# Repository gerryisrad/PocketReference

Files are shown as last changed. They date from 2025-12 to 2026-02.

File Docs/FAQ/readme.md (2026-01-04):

# PocketMage FAQ

---

#### Helpful Links

[PocketMage.org](https://pocketmage.org/)

[PocketMage - GitHub](https://github.com/ashtf8/PocketMage_PDA)

[PocketMage - Discord](https://discord.gg/KSCapSf4XH)

[Ashtf - YouTube](https://www.youtube.com/@ashtf)

[Ashtf - Patreon](patreon.com/Ashtf)

---

#### General Information

###### **What is PocketMage?**

PocketMage is a hackable PDA device focused on productivity. You can use it to take notes, keep track of tasks, journal, schedule your week, and much more. PocketMage is a hackable revival of the classic PDA-style device. The device features a dual-screen setup with a large E Ink main display and a smaller OLED secondary display. It also has a clamshell design with a clear shell and a full tactile thumb keyboard. PocketMage is fully open-source hardware and software, making it ideal for hacking and add-ons!

###### **How much is the kit?**

The PocketMage final production kit isn't released yet and the price isn't set in stone! That being said, the target price is around the $150 mark for a full kit.

###### **How hard is it to build the kit?**

The kit is designed so that **anyone can build it!** The only tool you need is one allen key, and the kit requires no special skills in software or hardware. There is **no soldering**, **no programming, and no electronics** involved in the build process.

###### **Will I be able to get PocketMage if I live outside the USA?**

We plan to ship PocketMage all around the world!

###### **When can I order?**

There is no set release date for the PocketMage kit at this moment, but once the beta production run is complete and the software has some time to mature, we will move on to the final production! See below for how to get notified when the kit releases!

###### **How can I get notified when the kit releases?**

Visit [PocketMage.org](https://pocketmage.org/) and click the purple "Join the Mailing List!" button to sign up for an email notification.

###### **How can I keep up with the PocketMage project?**

You can subscribe to [Ashtf's YouTube Channel](https://www.youtube.com/@ashtf) for video-style updates, [Ashtf's Patreon](patreon.com/Ashtf) for exclusive weekly written updates, and [The PocketMage Discord Server](https://discord.gg/KSCapSf4XH) for community-driven updates!

---

#### Building and Operating the PocketMage

###### **Where is the build guide?**

The video build guide can be found [here.](https://youtu.be/2aNcC0qCK1o?si=HKqUIyK0ZPkjqzQI)

###### **Is there a guide on the key operations?**

Yes! That guide can be found [here.](https://github.com/ashtf8/PocketMage_PDA/tree/main/Docs/Command%20Manual)

###### **How do I flash the firmware?**

First, carefully **remove the battery** out of your PocketMage (pull carefully on the plastic connector). Then, ensure the DIP switch for programming mode is switched to the ON position. Next, hold the power button while plugging your PocketMage into your computer, **nothing should happen**. Next, navigate to [The Web Flasher](https://ashtf8.github.io/PocketMage_PDA/) in a **chrome-based browser** and select your firmware version. The **most recent stable build** is recommended. If you would like to keep your saved settings, ensure that the "Preserve user data during installation" check box is **checked**. Next, hit the flash button and select the PocketMage from the list of USB devices. Once the flashing is done, unplug your PocketMage and re-insert the battery. PocketMage should boot up automatically!

###### **What SD card can I use?**

You can use any microSD card up to 32gb. **8gb is recommended** since PocketMage files are small and require very little storage. The smaller the SD card you use, the faster the PocketMage will be. SD cards **MUST** be formatted to **FAT32** format.

###### **Where are the CAD files?**

Currently CAD files are available only to Beta Testers. These files will be released to the public alongside the release of the final production PocketMage. If you are a Beta Tester, you can find the password-protected .zip file [here](https://github.com/ashtf8/PocketMage_PDA/tree/main/Docs/CAD) and the password in the beta Discord channel.

###### **Where can I get an extra battery?**

International kits do not come with a battery because of shipping regulations. Battery links for common countries can be found [here.](https://pocketmage.org/get/)

###### **What is the programming mode switch?**

The programming mode switch allows you to program and debug the PocketMage. Internally, it connects the USB port directly to the microcontroller, bypassing the USB and battery charge controller. You may keep programming mode on and use the device as normal with no issues, but your charging will be limited to 500mA as opposed to fast charging when programming mode is turned off.

#### Common Issues

---

###### **My dictionary isn't working!**

The English dictionary isn't installed on the PocketMage out of the box and needs to be downloaded to the SD card. Find the dictionary files [here.](https://github.com/ashtf8/PocketMage_PDA/tree/main/Docs/Dictionary%20(OPTED)) Simply connect your PocketMage to your computer using the USB app and drop all the .txt files into the dictionary folder!

###### **I can't flash the firmware!**

Ensure that: Your battery is unplugged and the programming mode DIP switch is set to ON.

###### **I found a software bug!**

Please report the bug in detail on the [GitHub issues page](https://github.com/ashtf8/PocketMage_PDA/issues) and include steps to reproduce. We will get to it when we can!

###### **My SD card isn't working!**

First, ensure that your SD card is below 32gb. The recommended size is 16gb, the smaller the SD card the faster the PocketMage will be. Next, ensure that your SD card is formatted to FAT32. It will not work unless it's formatted to FAT32.

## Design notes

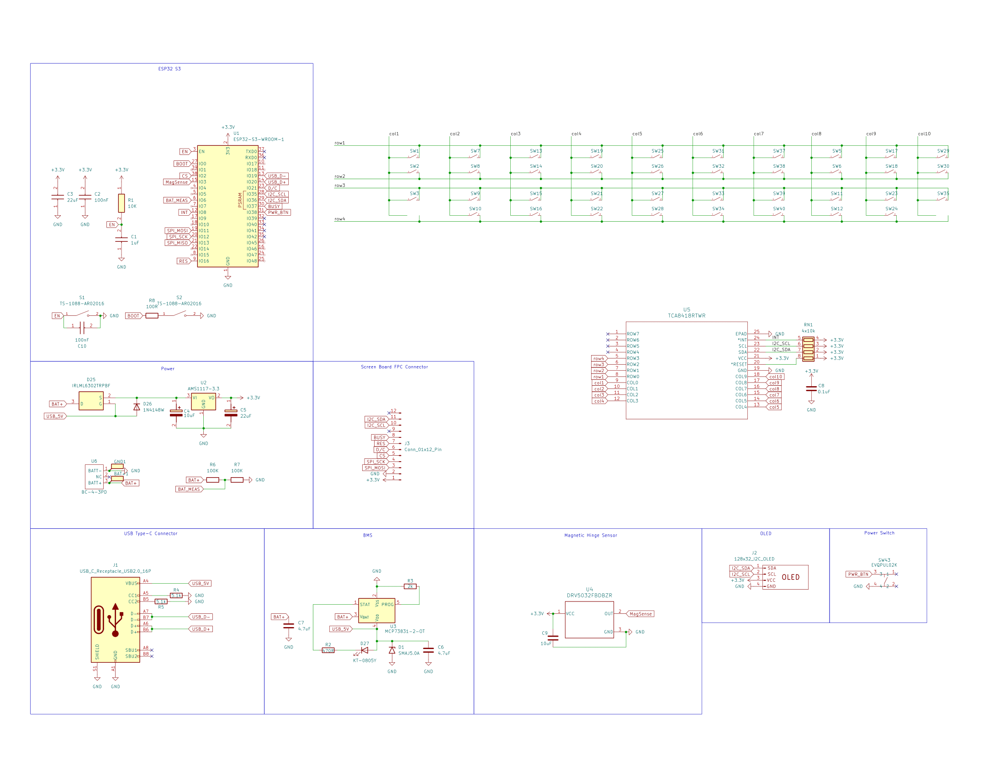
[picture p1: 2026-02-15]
Docs/Documents & Advanced/PCB/SCRAPPED V3/EXPORTED SVG/Schematic-1.png

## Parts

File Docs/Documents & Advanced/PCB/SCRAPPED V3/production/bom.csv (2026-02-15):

Designator | Footprint | Quantity | Value | LCSC Part #
BAT+1, GND1 | TestPoint_Pad_D1.5mm | 2 | TestPoint_Flag
C1 | CAPC2012X135N | 1 | 1uF | CL21B105KBFNNNE
C10, C2, C9 | CAPC2012X95N | 3 | 100nF | CC0805KRX7R9BB104
C3 | CAPC2012X140N | 1 | 22uF | CL21A226MAQNNNE
C4, C5, C6, C7 | 0805 | 4 | 4.7uF | CL21A475KAQNNNE
C8 | 0402 | 1 | 0.1uF | CL05B104KO5NNNC
D1 | D_SMA | 1 | SMAJ5.0A
D25 | SOT95P237X112-3N | 1 | IRLML6302TRPBF | IRLML6302TRPBF
D26 | D_SOD-123 | 1 | 1N4148W | 1N4148W
D27 | 0805 | 1 | KT-0805Y | KT-0805Y
J1 | USB_C_Receptacle_G-Switch_GT-USB-7010ASV | 1 | USB_C_Receptacle_USB2.0_16P | GT-USB-7010ASV
J2 | 128x32 I2C OLED | 1 | 128x32_I2C_OLED
J3 | AFC01-S12FCA-00 | 1 | Conn_01x12_Pin | AFC01-S12FCA-00:AFC01-S12FCA-00
R1, R9 | 0805 | 2 | 10K | 0805W8F1002T5E
R10 | 0603 | 1 | 20k | 0603WAF2002T5E
R11, R3 | 0805 | 2 | 2k | 0805W8F2001T5E
R2 | 0805 | 1 | 470R | 0805W8F4700T5E
R4, R5 | 0603 | 2 | 5.1k | 0603WAF5101T5E
R6, R7 | 1812 | 2 | 100K | FRC1812F1003TS
R8 | 1206 | 1 | 100R | 1206W4F1000T5E
RN1 | R_Array_Concave_4x0603 | 1 | 4x10k | 4D03WGJ0103T5E
S1, S2 | SW_TS-1088-AR02016 | 2 | TS-1088-AR02016 | TS-1088-AR02016
SW1, SW10, SW11, SW12, SW13, SW14, SW15, SW16, SW17, SW18, SW19, SW2, SW20, SW21, SW22, SW23, SW24, SW25, SW26, SW27, SW28, SW29, SW3, SW30, SW31, SW32, SW33, SW34, SW35, SW37, SW38, SW39, SW40, SW5, SW6, SW7, SW8, SW9 | contact_pad_SINGLE | 38 | ~
SW43 | EVQPUL02K | 1 | EVQPUL02K | EVQPUL02K
TP1, TP2 | TestPoint_Pad_3.0x3.0mm | 2 | TestPoint
U1 | ESP32-S3-WROOM-1 | 1 | ESP32-S3-WROOM-1 | ESP32-S3-WROOM-1
U2 | SOT-223-3_TabPin2 | 1 | AP2114H-3.3TRG1 | AP2114H-3.3TRG1
U3 | SOT-23-5 | 1 | MCP73831-2-OT | MCP73831-2-OT
U4 | SOIC-8_3.9x4.9mm_P1.27mm | 1 | PCF8563T
U5 | RTW24_2P45X2P45 | 1 | TCA8418RTWR | TCA8418RTWR
U6 | BC-4-3PD | 1 | BC-4-3PD | BC-4-3PD
Y1 | Crystal_SMD_3215-2Pin_3.2x1.5mm | 1 | Crystal_32.768kHz | XKXGI-SUA-32.768K

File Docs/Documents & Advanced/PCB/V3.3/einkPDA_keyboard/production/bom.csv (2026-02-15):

Designator | Footprint | Quantity | Value | LCSC Part #
BZ1 | BUZ-SMD_3P_L5.0-W5.0-P3.50-TL | 1 | Buzzer | C781883
C1, C20, C6 | 0603 | 3 | 1uF | C15849
C10, C23, C24, C26, C28, C29, C30, C31, C32 | 0805 | 9 | 10uF | C15850
C11 | 0603 | 1 | 4.7pF | C1669
C12, C13, C14, C16 | 1206 | 4 | 4.7uF | C29823
C15, C17 | 0805 | 2 | .1uF | C28233
C19, C7, C8 | 0402 | 3 | 0.1uF | C1525
C2, C9 | 0805 | 2 | 100nF | C49678
C21, C22, C3 | 0805 | 3 | 22uF | C45783
C25 | 0805 | 1 | 4.7uF | C1779
C27 | 0603 | 1 | 22nF | C21122
D1 | 0805 | 1 | KT-0805Y | C2296
D2 | D_SOD-123 | 1 | MBR0530 | C77336
D3 | D_SOD-123F | 1 | SM4007 | C64898
D5 | D_SOD-323 | 1 | D_Schottky | C191023
F1 | 1206 | 1 | SMD1206-500-6V | C2760308
FB1, FB2, FB3 | 0603 | 3 | FerriteBead | C85831
J1 | USB-TYPE-C-SMD_TYPE-C-16P-QTWT | 1 | USB_C_Receptacle_USB2.0_16P | C5187472
J2, J5 | AFC01-S12FCA-00 | 2 | Conn_01x12_Pin | C262661
J3 | FPC-SMD_AFC24-S26FIA [DUAL-SIDE] | 1 | Conn_01x26_Pin | C262684
J4 | TF-SMD_503398-1892 | 1 | Micro_SD_Card | C428492
L1 | L_Chilisin_BMRx00060630 | 1 | 10uH | C5189958
L2 | L_Ferrocore_DLG-0504 | 1 | 1uH | C2929426
L3 | L_Wurth_WE-LQSH-3012 | 1 | 2.2uH | C19734
Q1 | SOT-23 | 1 | MMBT3904 | C20526
R1, R14, R17, R9 | 0805 | 4 | 10K | C17414
R10 | 0603 | 1 | 20k | C4184
R11, R16 | 0805 | 2 | 2k | C17604
R12 | 0805 | 1 | 1.8M | C17399
R13 | 0805 | 1 | 205k | C218417
R15 | 0805 | 1 | 470R | C17710
R18 | 0603 | 1 | 10k | C25804
R2, R8 | 0603 | 2 | 100R | C22775
R20 | 0805 | 1 | 680k | C17797
R3 | 0603 | 1 | 4.7k | C23162
R6, R7 | 0603 | 2 | 100K | C25803
RN1, RN2, RN3, RN4 | R_Array_Concave_4x0603 | 4 | 4x10k | C29718
SW1, SW10, SW11, SW12, SW13, SW14, SW15, SW16, SW17, SW18, SW19, SW20, SW21, SW22, SW23, SW24, SW25, SW26, SW27, SW28, SW29, SW3, SW30, SW31, SW32, SW33, SW34, SW35, SW37, SW38, SW39, SW40, SW5, SW6, SW7, SW9 | contact_pad_SINGLE | 36 | ~
SW2 | contactPad_cutoutR | 1 | ~
SW4 | 2X_DIP_DHN-02-V-TR | 1 | SW_DIP_x02 | C224995
SW43 | SW-SMD_TS24CA | 1 | EVQPUL02K | C393942
SW8 | contactPad_cutoutL | 1 | ~
TH1 | 0603 | 1 | NTC | C76589
TP1, TP2 | TestPoint_Pad_1.0x1.0mm | 2 | TestPoint
U1 | ESP32-S3-WROOM-1 | 1 | ESP32-S3-WROOM-1 | C2913202
U10 | UQFN-10_1.4x1.8mm_P0.4mm | 1 | TS3USB30ERSWR | C73880
U2 | SOT-23-6 | 1 | USBLC6-2SC6 | C7519
U3 | Texas_DRC0010J_ThermalVias | 1 | TPS63001 | C28060
U4 | SOIC-8_3.9x4.9mm_P1.27mm | 1 | PCF8563T | C7440
U5 | RTW24_2P45X2P45 | 1 | TCA8418RTWR | C138713
U6 | JST_PH_2P_P2.00mm | 1 | C2764211 | C2764211
U7 | SOT-23-5 | 1 | TPS61040DBV | C7722
U9 | IC_MP2722GRH-0000-Z | 1 | MP2722GRH-0000-Z | C20099551
Y1 | Crystal_SMD_3215-2Pin_3.2x1.5mm | 1 | Crystal_32.768kHz | C5213671

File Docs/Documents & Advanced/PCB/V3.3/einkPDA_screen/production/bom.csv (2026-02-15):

Designator | Footprint | Quantity | Value | LCSC Part #
C1, C10, C3, C4, C5, C6, C7, C8, C9 | 0402 | 9 | 1uF | CL05A105KA5NQNC
C11 | 0805 | 1 | 4.7uF | CL21A475KAQNNNE
C12, C2 | 0402 | 2 | 4.7uF | CL05A475MP5NRNC
C13, C14 | 0402 | 2 | 0.1uF | CL05B104KO5NNNC
D1, D2, D3 | D_SOD-123 | 3 | MBR0530 | MBR0530
J2 | AFE03-S25FMA-1H | 1 | ~ | AFE03-S25FMA-1H
J3 | TouchSlider-9_50x10mm | 1 | CapacitiveTouch
J4 | AFC01-S12FCA-00 | 1 | Conn_01x12_Pin | AFC01-S12FCA-00
L1 | L_Cenker_CKCS5020 | 1 | 10uH | SWPA5020S100MT
Q1 | SOT-323_SC-70 | 1 | Si1308EDL | Si1308EDL
R1 | 0603 | 1 | 1R | 0603WAF100KT5E
R2 | 0805 | 1 | 10k | 0805W8F1002T5E
R3 | 0603 | 1 | 75k | 0603WAF7502T5E
RN1 | R_Array_Concave_4x0603 | 1 | 4x10k | 4D03WGJ0103T5E
U1 | UQFN-20_3x3mm_P0.4mm | 1 | MPR121QR2 | MPR121QR2

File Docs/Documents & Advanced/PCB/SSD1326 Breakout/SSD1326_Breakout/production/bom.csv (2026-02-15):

Designator | Footprint | Quantity | Value | LCSC Part #
C1 | 0805 | 1 | 10uF
C2, C6 | 1206 | 2 | 4.7uF
C3 | 0603 | 1 | 4.7pF
C4, C5 | CP_EIA-3216-18_Kemet-A | 2 | 4.7uF
C7, C8 | 0805 | 2 | .1uF
D1 | D_SOD-123 | 1 | MBR0530
J1 | FPC-SMD_AFC24-S26FIA [DUAL-SIDE] | 1 | Conn_01x26_Pin
J2 | PinHeader_1x05_P2.54mm_Vertical | 1 | Conn_01x05_Pin
L1 | L_Chilisin_BMRx00060630 | 1 | 10uH
R1 | 0805 | 1 | 1.8M
R2 | 0805 | 1 | 205k
R3, R4 | 0805 | 2 | 10k
R5 | 0805 | 1 | 680k
U1 | SOT-23-5 | 1 | TPS61040DBV

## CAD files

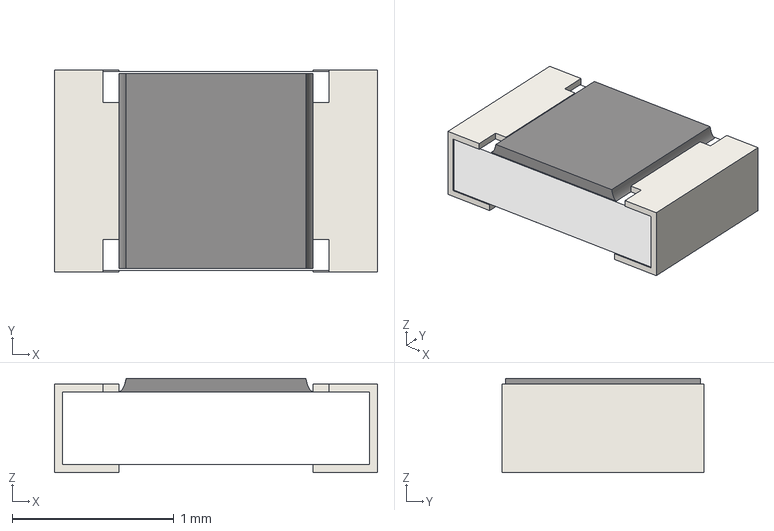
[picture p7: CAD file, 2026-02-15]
Docs/Documents & Advanced/PCB/SCRAPPED V3/import/LIB_0805W8F1002T5E/0805W8F1002T5E/3D/0805W8F1002T5E.stp
2.00 x 1.25 x 0.585 mm

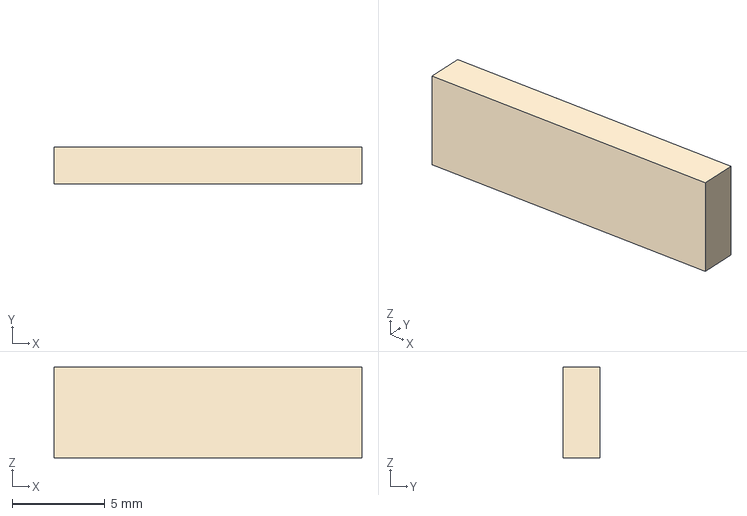
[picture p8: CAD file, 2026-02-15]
Docs/Documents & Advanced/PCB/V3.3/C262684 v2.step
16.6 x 2.00 x 4.90 mm

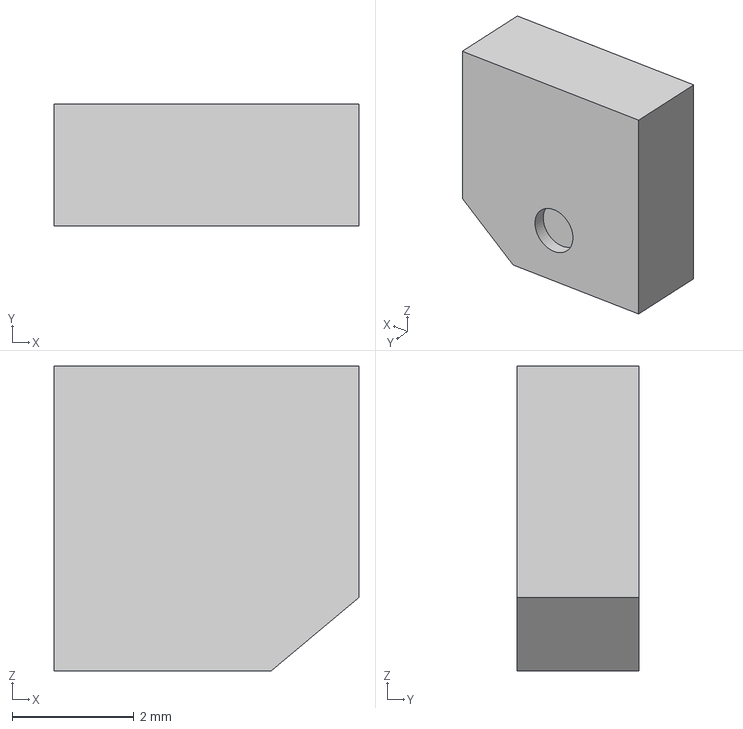
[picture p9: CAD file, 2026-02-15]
Docs/Documents & Advanced/PCB/V3.3/einkPDA_keyboard/JLC_Parts/C781883 v1.step
5.00 x 2.00 x 5.00 mm

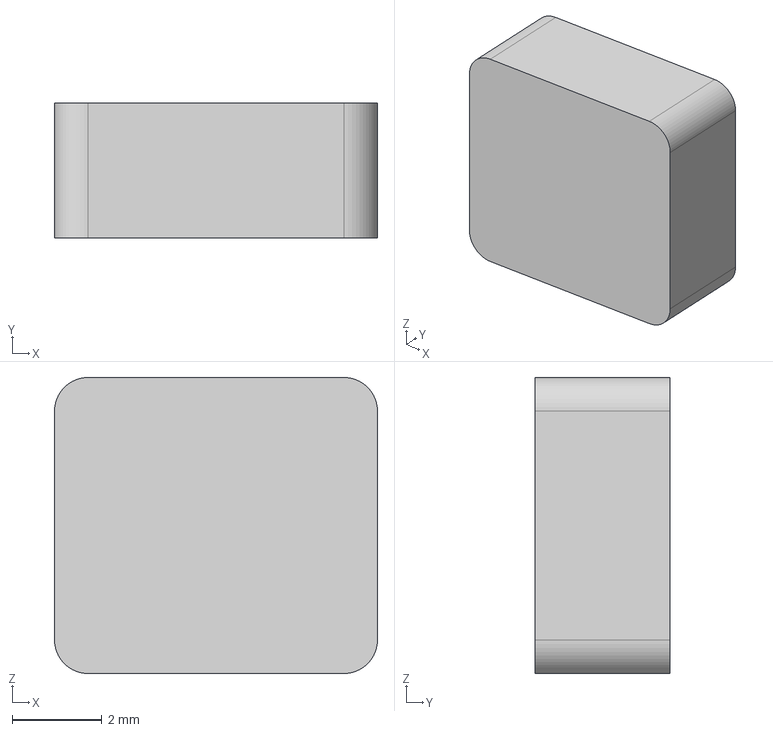
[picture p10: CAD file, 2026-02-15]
Docs/Documents & Advanced/PCB/V3.3/einkPDA_keyboard/JLC_Parts/C5189958 v3.step
7.20 x 3.00 x 6.60 mm

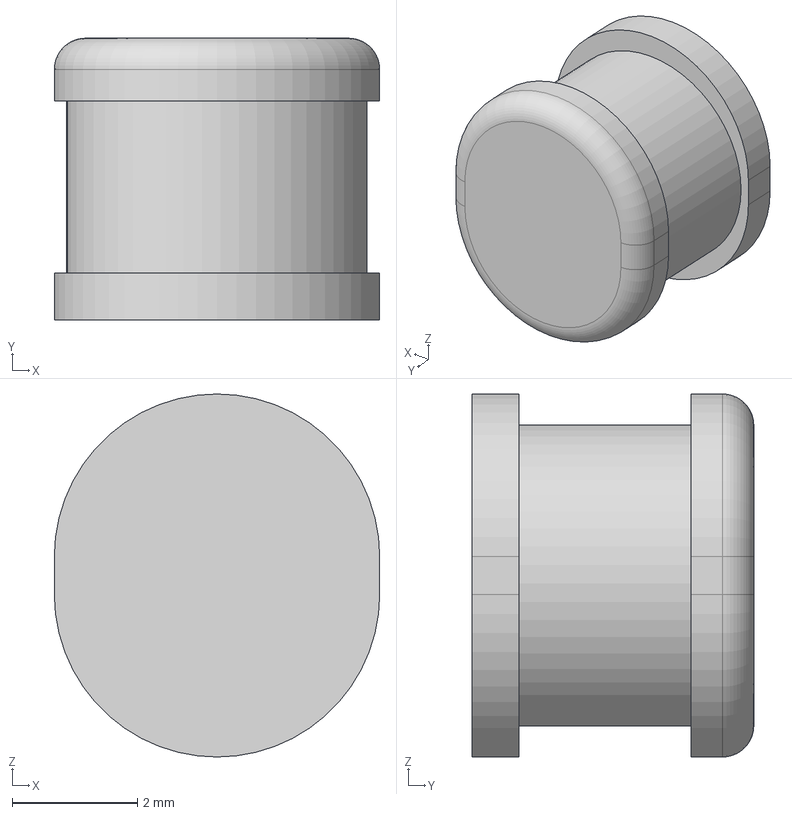
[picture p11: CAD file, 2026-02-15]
Docs/Documents & Advanced/PCB/V3.3/einkPDA_keyboard/JLC_Parts/C2929426 v4.step
5.20 x 4.50 x 5.80 mm

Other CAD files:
Docs/Documents & Advanced/PCB/SCRAPPED V3/import/LIB_0805W8F1002T5E/0805W8F1002T5E/Allegro/resc2013x65n.psm
Docs/Documents & Advanced/PCB/SCRAPPED V3/import/LIB_0805W8F1002T5E/0805W8F1002T5E/DEHDL/0805w8f1002t5e/chips/chips.prt
Docs/Documents & Advanced/PCB/V1/einkPDA_keyboard/import/LIB_0805W8F1002T5E/0805W8F1002T5E/Allegro/resc2013x65n.psm
Docs/Documents & Advanced/PCB/V1/einkPDA_keyboard/import/LIB_0805W8F1002T5E/0805W8F1002T5E/DEHDL/0805w8f1002t5e/chips/chips.prt
Docs/Documents & Advanced/PCB/V2/einkPDA_keyboard/import/LIB_0805W8F1002T5E/0805W8F1002T5E/Allegro/resc2013x65n.psm
Docs/Documents & Advanced/PCB/V2/einkPDA_keyboard/import/LIB_0805W8F1002T5E/0805W8F1002T5E/DEHDL/0805w8f1002t5e/chips/chips.prt
Docs/Documents & Advanced/PCB/V3.1/einkPDA_keyboard/import/LIB_0805W8F1002T5E/0805W8F1002T5E/Allegro/resc2013x65n.psm
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

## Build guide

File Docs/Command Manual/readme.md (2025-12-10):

# PocketMage Keystrokes Guide
This is a guide on common key combinations and commands on the PocketMage PDA device. The guide is split up into sections based on application.

---
## General Keystrokes (work in almost any app)
- **(FN) + ( < )** | Exit or back button
- **(FN) + ( > )** | Save document
- **(FN) + ( o )** | Clear Line
- **(FN) + (Key)** | FN layer keymapping (legends on the PCB)
- **(SHFT) + (key)** | Capital letter
- **( o ) OR (ENTER)** | Select button

---
## Home App
### Entering an OS app
Type an app's name to enter that app. For example, to enter calendar, type "calendar". You can type the name as it appears on the screen or use a shortcut. For example, typing "cal" also enters the calendar.

### Entering a 3rd party app
For 3rd party apps, type the letter of the slot that app is installed in. For example if you have the Calc app installed in the first app slot, type "a" to enter the app.

### Other commands
Many other commands can be done from the homescreen, including all of the settings commands and some other fun ones for you to discover!

---
## TXT App
- **(FN) + ( < )** | Exit app
- **(FN) + ( > )** | Save document
- **(FN) + ( o )** | Enter filesystem (loading files)
- **(FN) + (Key)** | FN layer keymapping (legends on the PCB)
- **(SHFT) + (key)** | Capital letter
- **(ENTER)** | Create a new line
- **(SHFT) + ( < )** | Change text style (body, heading, etc.)
- **(SHFT) + ( > )** | Change formatting (bold, italics, etc.)
- **Scroll Bar** | Swipe up or down to scroll through the document

---
## FILEWIZ
- **(FN) + ( < )** | Exit app
- **( < ) AND ( > )** | Scroll left and right
- **( o ) OR (ENTER)** | Select file or folder
- **( 0 ) TO ( 9 )** | Select recent file
- **( BKSP )** | Go back a filesystem level

---
## USB
Plug in the PocketMage to your PC to view the files. Eject and exit the app when you're finished.
- **(FN) + ( < )** | Exit app

---
## Settings
Type the setting as it appears on the screen to change it. Some examples are given below. Note: all settings are case-insensitive, meaning that you can type in all lowercase. All of these settings are also available from the home menu command bar if you memorize them.
- TimeSet [HH]:[MM] -> TimeSet 15:46
- DateSet YYYYMMDD -> DateSet 20251230
- ShowYear [bool] -> ShowYear t
- Timeout [int] -> Timeout 300
- **(FN) + ( < )** | Exit app

---
## Tasks
- **( N )** | Create a new task, follow on-screen prompts
- **(ENTER)** | Enter information into prompt
- **( 0 ) TO ( 9 )** | Select task for editing
- **(FN) + ( < )** | Exit app

---
## Calendar
Type commands to navigate dates or create events. All commands are case-insensitive.

### Month View
- **jan 2025 / feb 2030 / etc.** | Jump to month and year
- **20251225** | Jump to exact date (YYYYMMDD)
- **14** | Jump to a day in the current month
- **( N )** | New event
- **(FN) + ( < )** | Exit app

### Week View
- **sun, mon, tue, wed, thu, fri, sat** | Jump to weekday in the viewed week
- **( N )** | New event
- **(FN) + ( < )** | Exit app

### Day View
- **( N )** | New event for selected day
- **1, 2, 3, ...** | Open event by index
- **(FN) + ( < )** | Exit app

---
## Journal
Type a date to open or create a journal entry. Commands are case-insensitive.

- **( T )** | Open today’s journal entry
- **YYYYMMDD - Example: 20250314** | Open/create entry for exact date
- **jan 1 / feb 12 / etc.** | Open/create entry for given month and day (uses current year)
- **(FN) + ( < )** | Exit app

---
## Lexicon
Type a word to search the dictionary. Matches are loaded from the SD card. Commands are case-insensitive.

- **Type any word** | Search for definitions (example: abandon)
- **(ENTER)** | Execute search
- **( < ) OR ( > )** | Previous / next definition
- **(FN) + ( < )** | Exit app

---
## App loader
Manage and install .tar apps to OTA slots. Commands are case-insensitive.
- **A / B / C / D** | Select OTA slot to edit
- **( S )** | Swap app in selected slot (choose a .tar file)
- **( D )** | Delete app in selected slot
- **(FN) + ( < )** | Exit app / return to menu
- **Progress Bar** | Shows extraction (0–50%) and installation (50–100%) status

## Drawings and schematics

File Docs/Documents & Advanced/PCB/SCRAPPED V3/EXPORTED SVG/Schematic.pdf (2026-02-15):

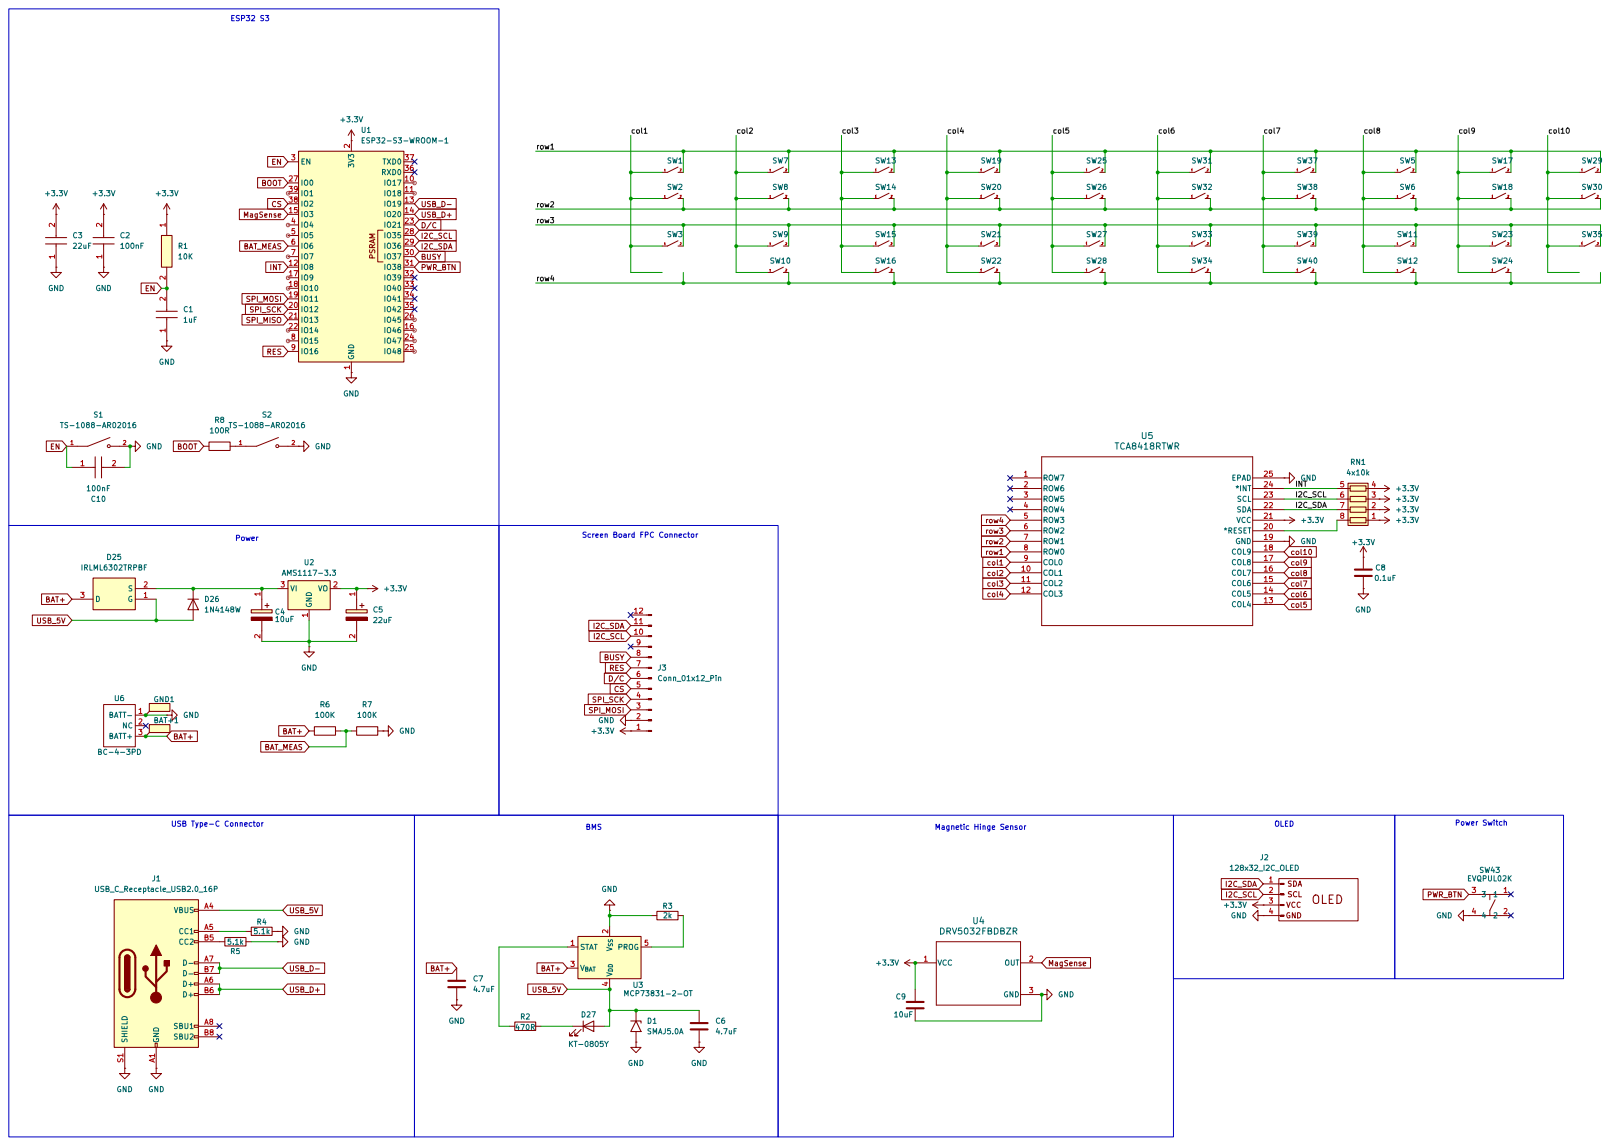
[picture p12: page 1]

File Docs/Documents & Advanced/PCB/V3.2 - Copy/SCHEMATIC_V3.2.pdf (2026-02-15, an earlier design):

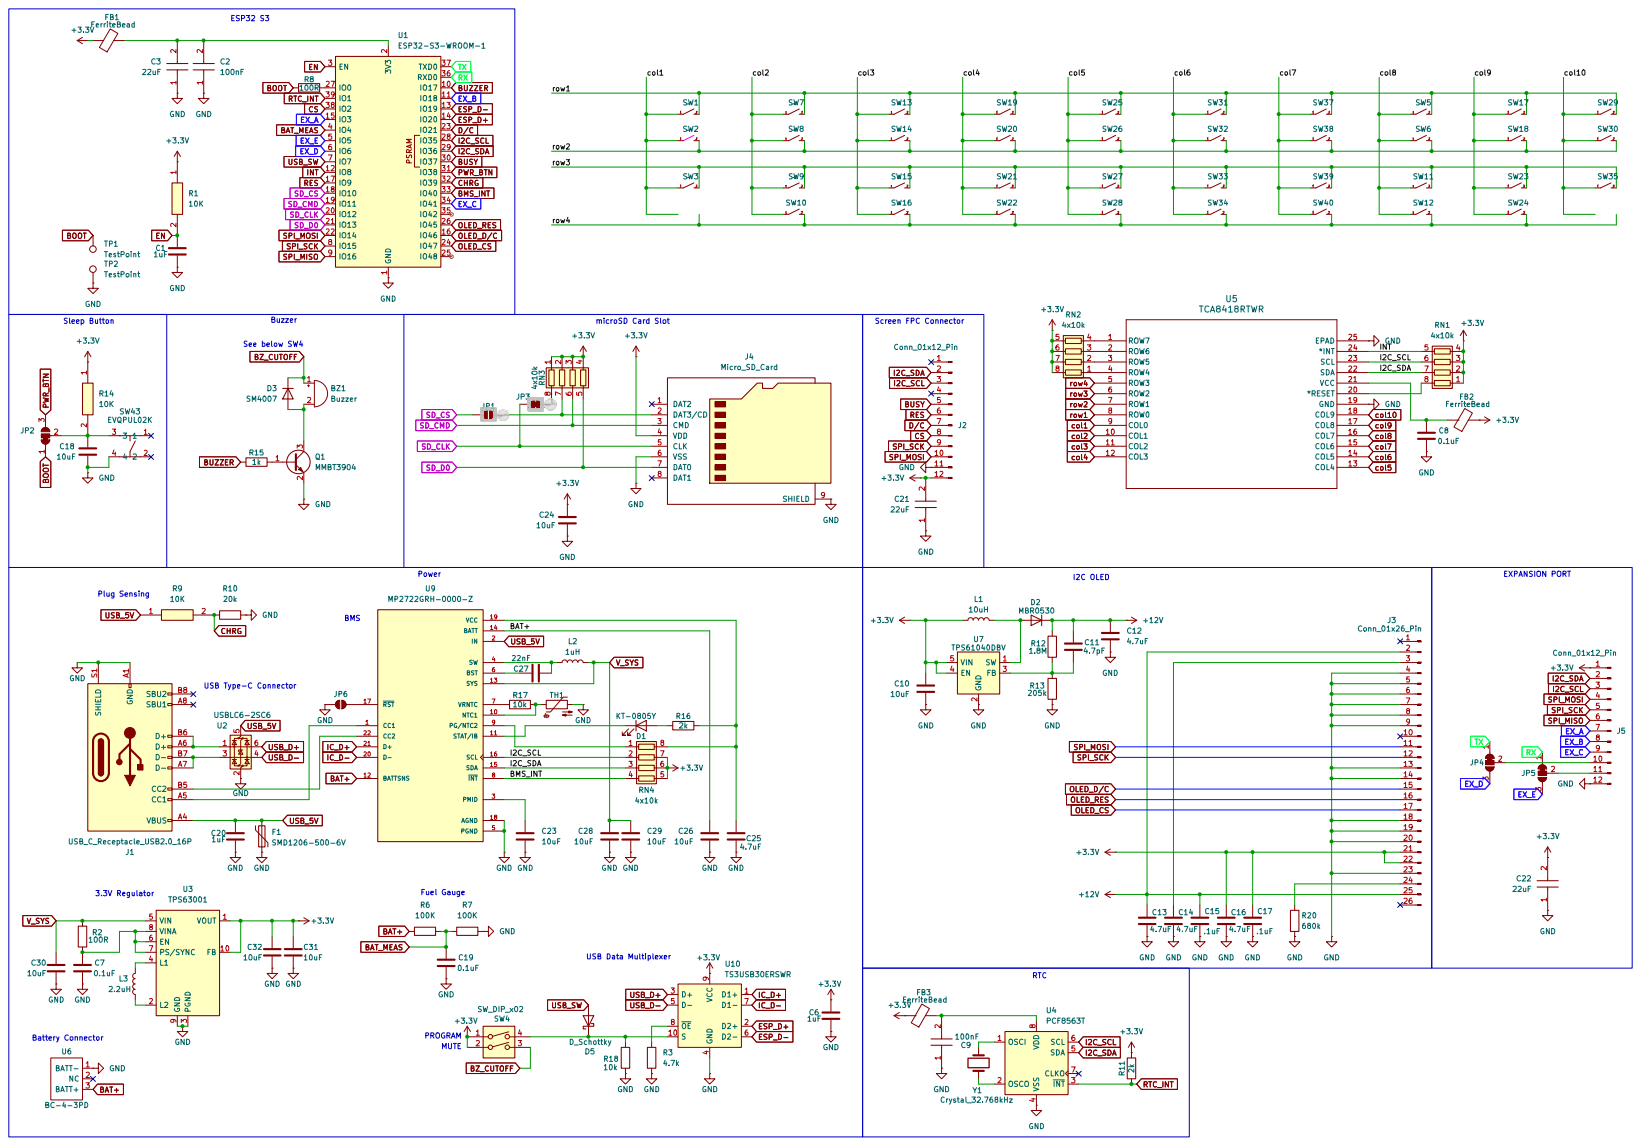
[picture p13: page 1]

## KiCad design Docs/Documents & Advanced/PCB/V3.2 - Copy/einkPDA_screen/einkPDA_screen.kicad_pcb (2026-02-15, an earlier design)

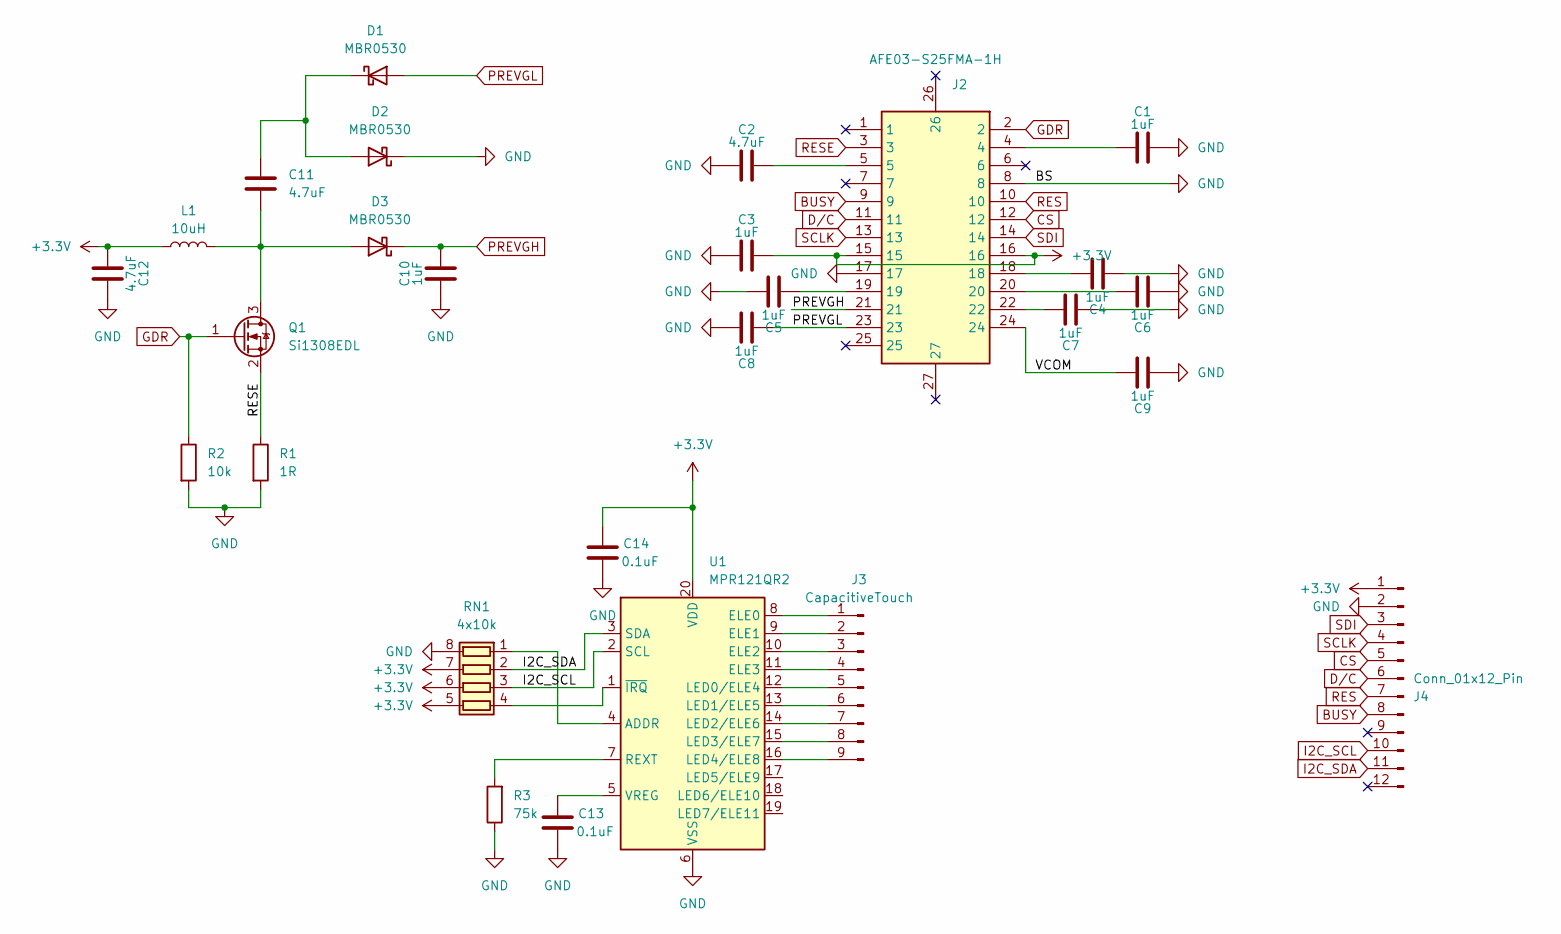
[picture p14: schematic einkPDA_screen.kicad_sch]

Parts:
C1, C3, C4, C5, C6, C7, C8, C9, C10: 1uF; C_0402_1005Metric; MPN CL05A105KA5NQNC
C2, C12: 4.7uF; C_0402_1005Metric; MPN CL05A475MP5NRNC
C11: 4.7uF; C_0805_2012Metric; MPN CL21A475KAQNNNE
C13, C14: 0.1uF; C_0402_1005Metric; MPN CL05B104KO5NNNC
D1, D2, D3: MBR0530; D_SOD-123; MPN MBR0530
J2: AFE03-S25FMA-1H; MPN AFE03-S25FMA-1H
J3: CapacitiveTouch; TouchSlider-9_50x10mm
J4: Conn_01x12_Pin; AFC01-S12FCA-00; MPN AFC01-S12FCA-00
L1: 10uH; L_Cenker_CKCS5020; MPN SWPA5020S100MT
Q1: Si1308EDL; SOT-323_SC-70; MPN Si1308EDL
R1: 1R; R_0603_1608Metric; MPN 0603WAF100KT5E
R2: 10k; R_0805_2012Metric; MPN 0805W8F1002T5E
R3: 75k; R_0603_1608Metric; MPN 0603WAF7502T5E
RN1: 4x10k; R_Array_Concave_4x0603; MPN 4D03WGJ0103T5E
U1: MPR121QR2; UQFN-20_3x3mm_P0.4mm; MPN MPR121QR2

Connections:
+3.3V: C3.2, C12.1, C14.1, J2.15, J2.16, J4.1, L1.1, RN1.5 (R4.2), RN1.6 (R3.2), RN1.7 (R2.2), U1.20 (VDD)
/VCOM: C9.2, J2.24
BUSY: J2.9, J4.8
CS: J2.12, J4.5
D/C: J2.11, J4.6
GDR: J2.2, Q1.1 (G), R2.1
GND: C1.2, C2.1, C3.1, C4.1, C5.2, C6.1, C7.1, C8.2, C9.1, C10.1, C12.2, C13.2, C14.2, D2.1 (K), J2.8, J2.17, J4.2, R1.2, R2.2, R3.1, RN1.8 (R1.2), U1.6 (VSS)
I2C_SCL: J4.10, RN1.3 (R3.1), U1.2 (SCL)
I2C_SDA: J4.11, RN1.2 (R2.1), U1.3 (SDA)
unnamed: C1.1, J2.4
unnamed: C2.2, J2.5
unnamed: C4.2, J2.18
unnamed: C5.1, J2.19
unnamed: C6.2, J2.20
unnamed: C7.2, J2.22
unnamed: C11.1, D1.1 (K), D2.2 (A)
unnamed: C11.2, D3.2 (A), L1.2, Q1.3 (D)
unnamed: J3.1, U1.8 (ELE0)
unnamed: J3.2, U1.9 (ELE1)
unnamed: J3.3, U1.10 (ELE2)
unnamed: J3.4, U1.11 (ELE3)
unnamed: J3.5, U1.12 (LED0/ELE4)
unnamed: J3.6, U1.13 (LED1/ELE5)
unnamed: J3.7, U1.14 (LED2/ELE6)
unnamed: J3.8, U1.15 (LED3/ELE7)
unnamed: J3.9, U1.16 (LED4/ELE8)
unnamed: RN1.1 (R1.1), U1.4 (ADDR)
unnamed: RN1.4 (R4.1), U1.1 (~IRQ)
unnamed: R3.2, U1.7 (REXT)
unnamed: C13.1, U1.5 (VREG)
PREVGH: C10.2, D3.1 (K), J2.21
PREVGL: C8.1, D1.2 (A), J2.23
RES: J2.10, J4.7
RESE: J2.3, Q1.2 (S), R1.1
SCLK: J2.13, J4.4
SDI: J2.14, J4.3

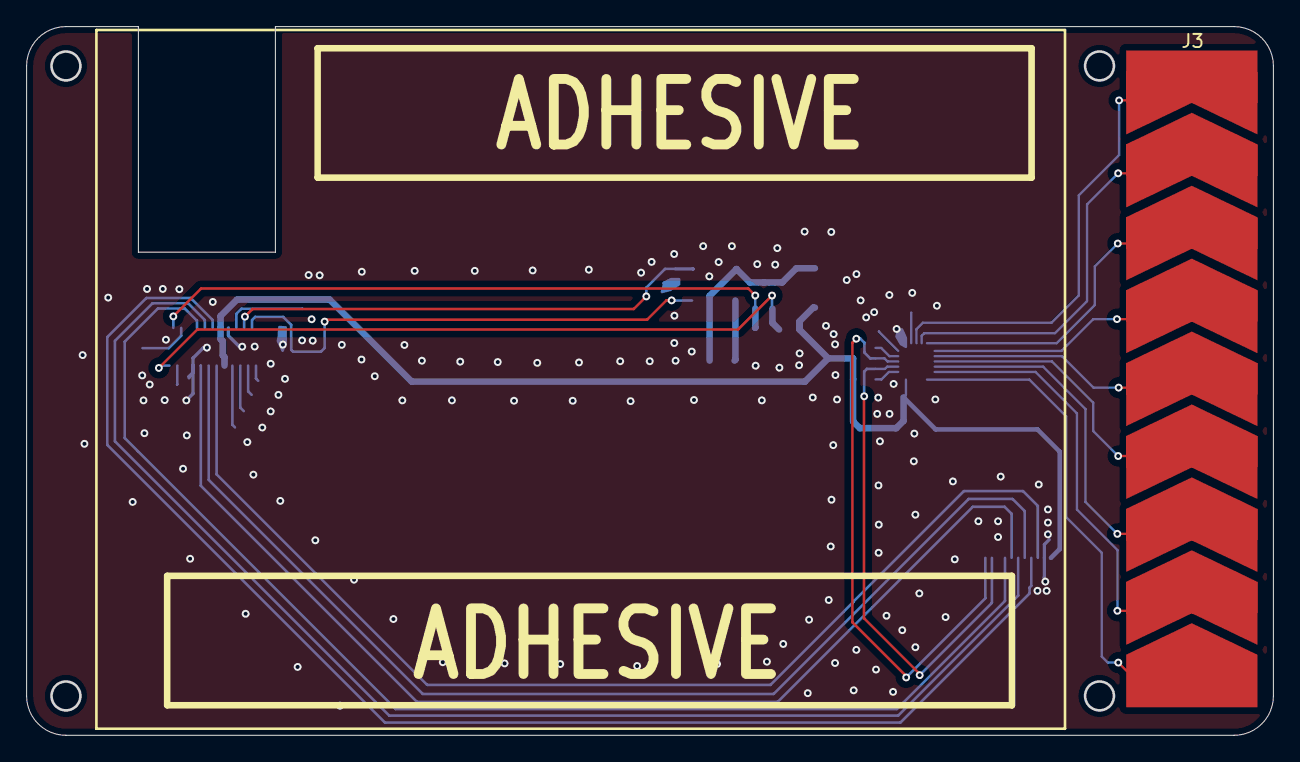
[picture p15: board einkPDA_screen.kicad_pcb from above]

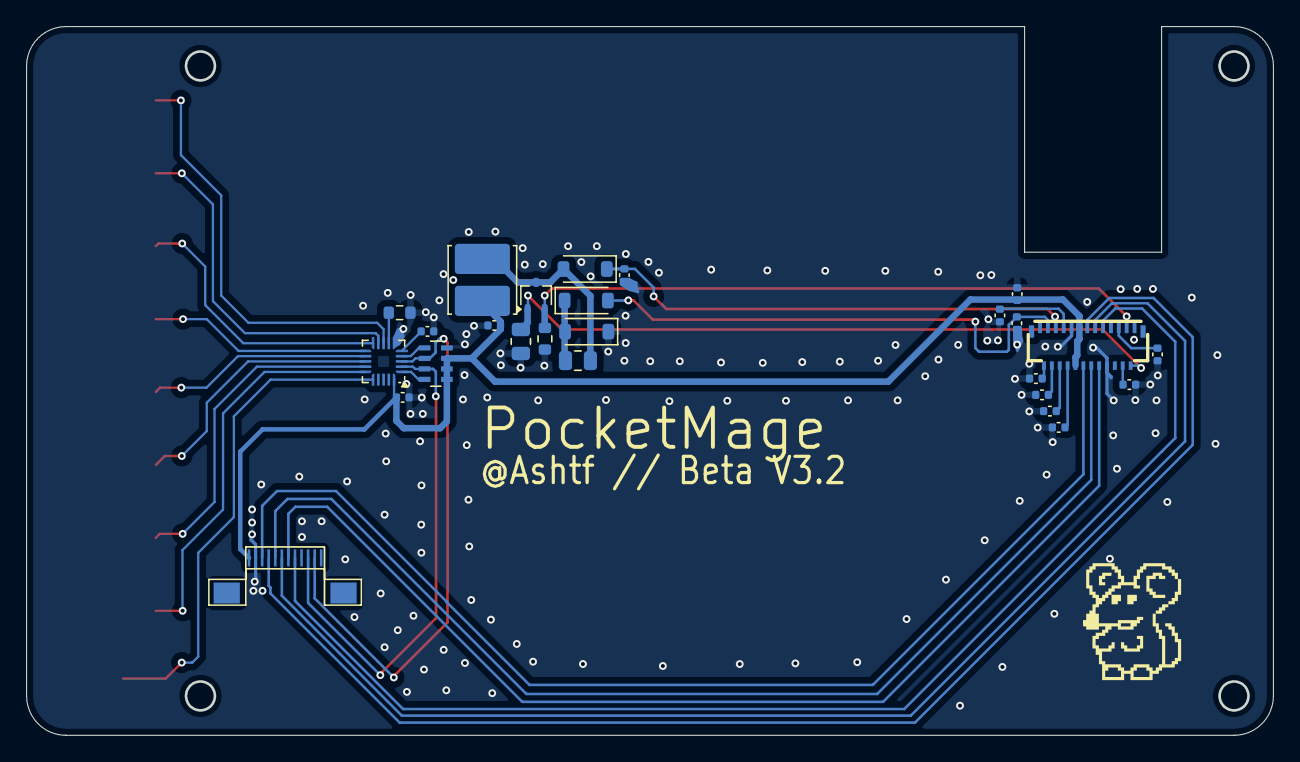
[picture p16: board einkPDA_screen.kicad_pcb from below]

Board: 2 copper layers, 95.0 x 54.0 mm, 27 parts (26 on the bottom side), 36 nets.

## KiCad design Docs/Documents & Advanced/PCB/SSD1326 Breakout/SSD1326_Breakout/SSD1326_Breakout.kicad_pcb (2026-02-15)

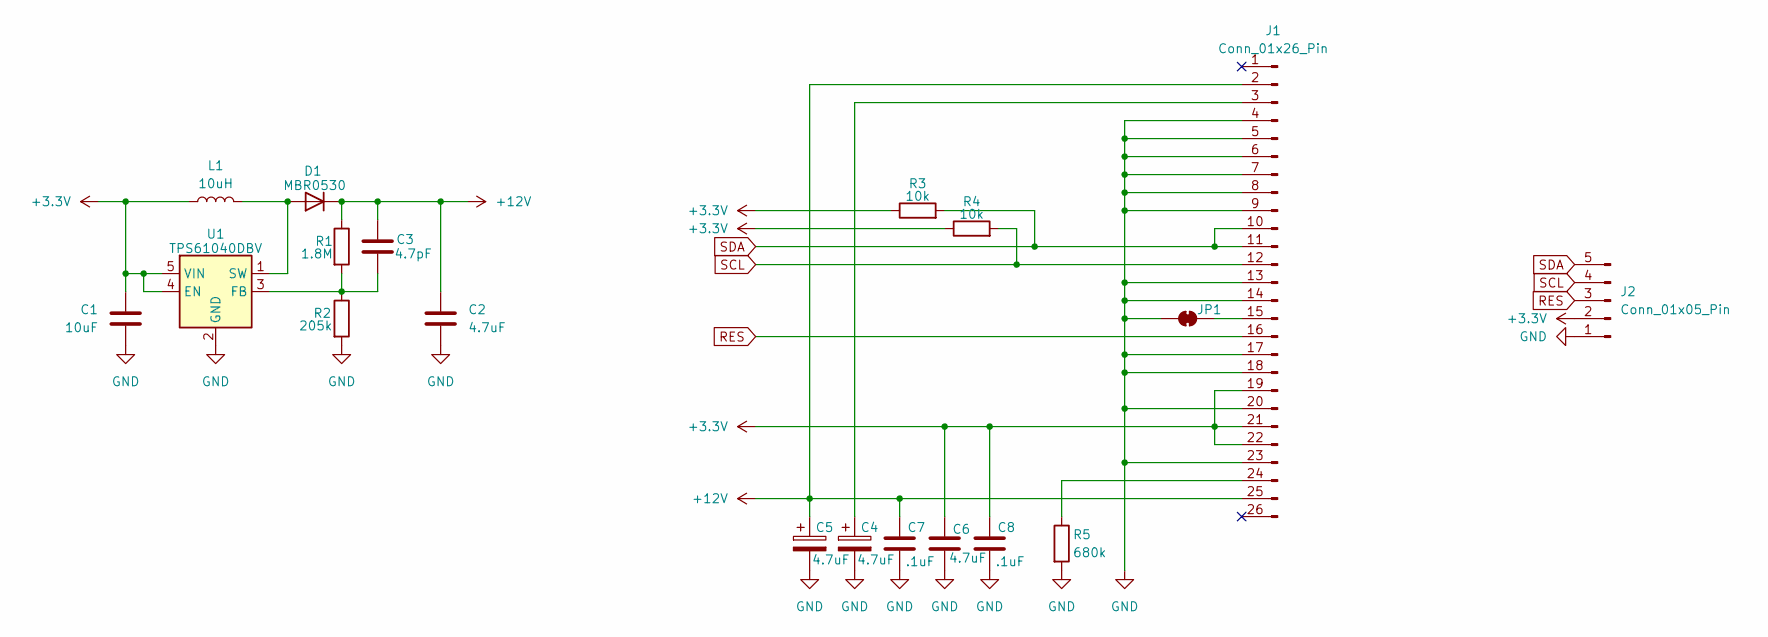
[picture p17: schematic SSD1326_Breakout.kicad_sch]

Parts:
C1: 10uF; C_0805_2012Metric; LCSC PART # C15850
C2, C6: 4.7uF; C_1206_3216Metric; LCSC PART # C29823
C3: 4.7pF; C_0603_1608Metric; LCSC PART # C1669
C4, C5: 4.7uF; CP_EIA-3216-18_Kemet-A; LCSC PART # C7189
C7, C8: .1uF; C_0805_2012Metric; LCSC PART # C28233
D1: MBR0530; D_SOD-123; LCSC PART # C77336
J1: Conn_01x26_Pin; FPC-SMD_AFC24-S26FIA [DUAL-SIDE]; LCSC PART # C262684
J2: Conn_01x05_Pin; PinHeader_1x05_P2.54mm_Vertical
JP1: SolderJumper_2_Bridged; SolderJumper-2_P1.3mm_Bridged_RoundedPad1.0x1.5mm
L1: 10uH; L_Chilisin_BMRx00060630; LCSC PART # C5189958
R1: 1.8M; R_0805_2012Metric; LCSC PART # C17399
R2: 205k; R_0805_2012Metric; LCSC PART # C218417
R3, R4: 10k; R_0805_2012Metric; LCSC PART # C17414
R5: 680k; R_0805_2012Metric; LCSC PART # C17797
U1: TPS61040DBV; SOT-23-5; LCSC PART # C7722

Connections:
+3.3V: C1.2, C6.1, C8.1, J1.19, J1.21, J1.22, J2.2, L1.1, R3.1, R4.1, U1.4 (EN), U1.5 (VIN)
+12V: C2.1, C3.2, C5.1, C7.1, D1.1 (K), J1.2, J1.25, R1.1
GND: C1.1, C2.2, C4.2, C5.2, C6.2, C7.2, C8.2, J1.4, J1.5, J1.6, J1.7, J1.8, J1.9, J1.13, J1.14, J1.17, J1.18, J1.20, J1.23, J2.1, JP1.1 (A), R2.2, R5.2, U1.2 (GND)
unnamed: D1.2 (A), L1.2, U1.1 (SW)
unnamed: C4.1, J1.3
unnamed: J1.15, JP1.2 (B)
unnamed: J1.24, R5.1
unnamed: C3.1, R1.2, R2.1, U1.3 (FB)
RES: J1.16, J2.3
SCL: J1.12, J2.4, R4.2
SDA: J1.10, J1.11, J2.5, R3.2

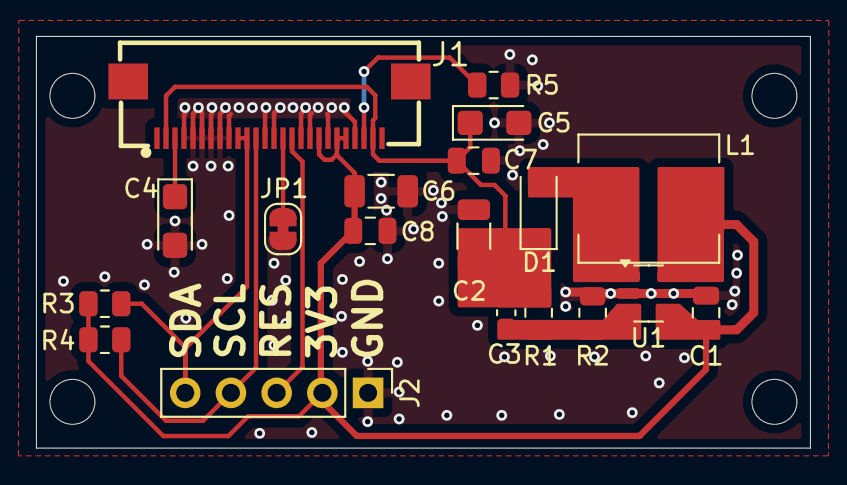
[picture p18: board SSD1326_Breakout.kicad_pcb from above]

Board: 2 copper layers, 43.0 x 22.9 mm, 19 parts (0 on the bottom side), 11 nets.

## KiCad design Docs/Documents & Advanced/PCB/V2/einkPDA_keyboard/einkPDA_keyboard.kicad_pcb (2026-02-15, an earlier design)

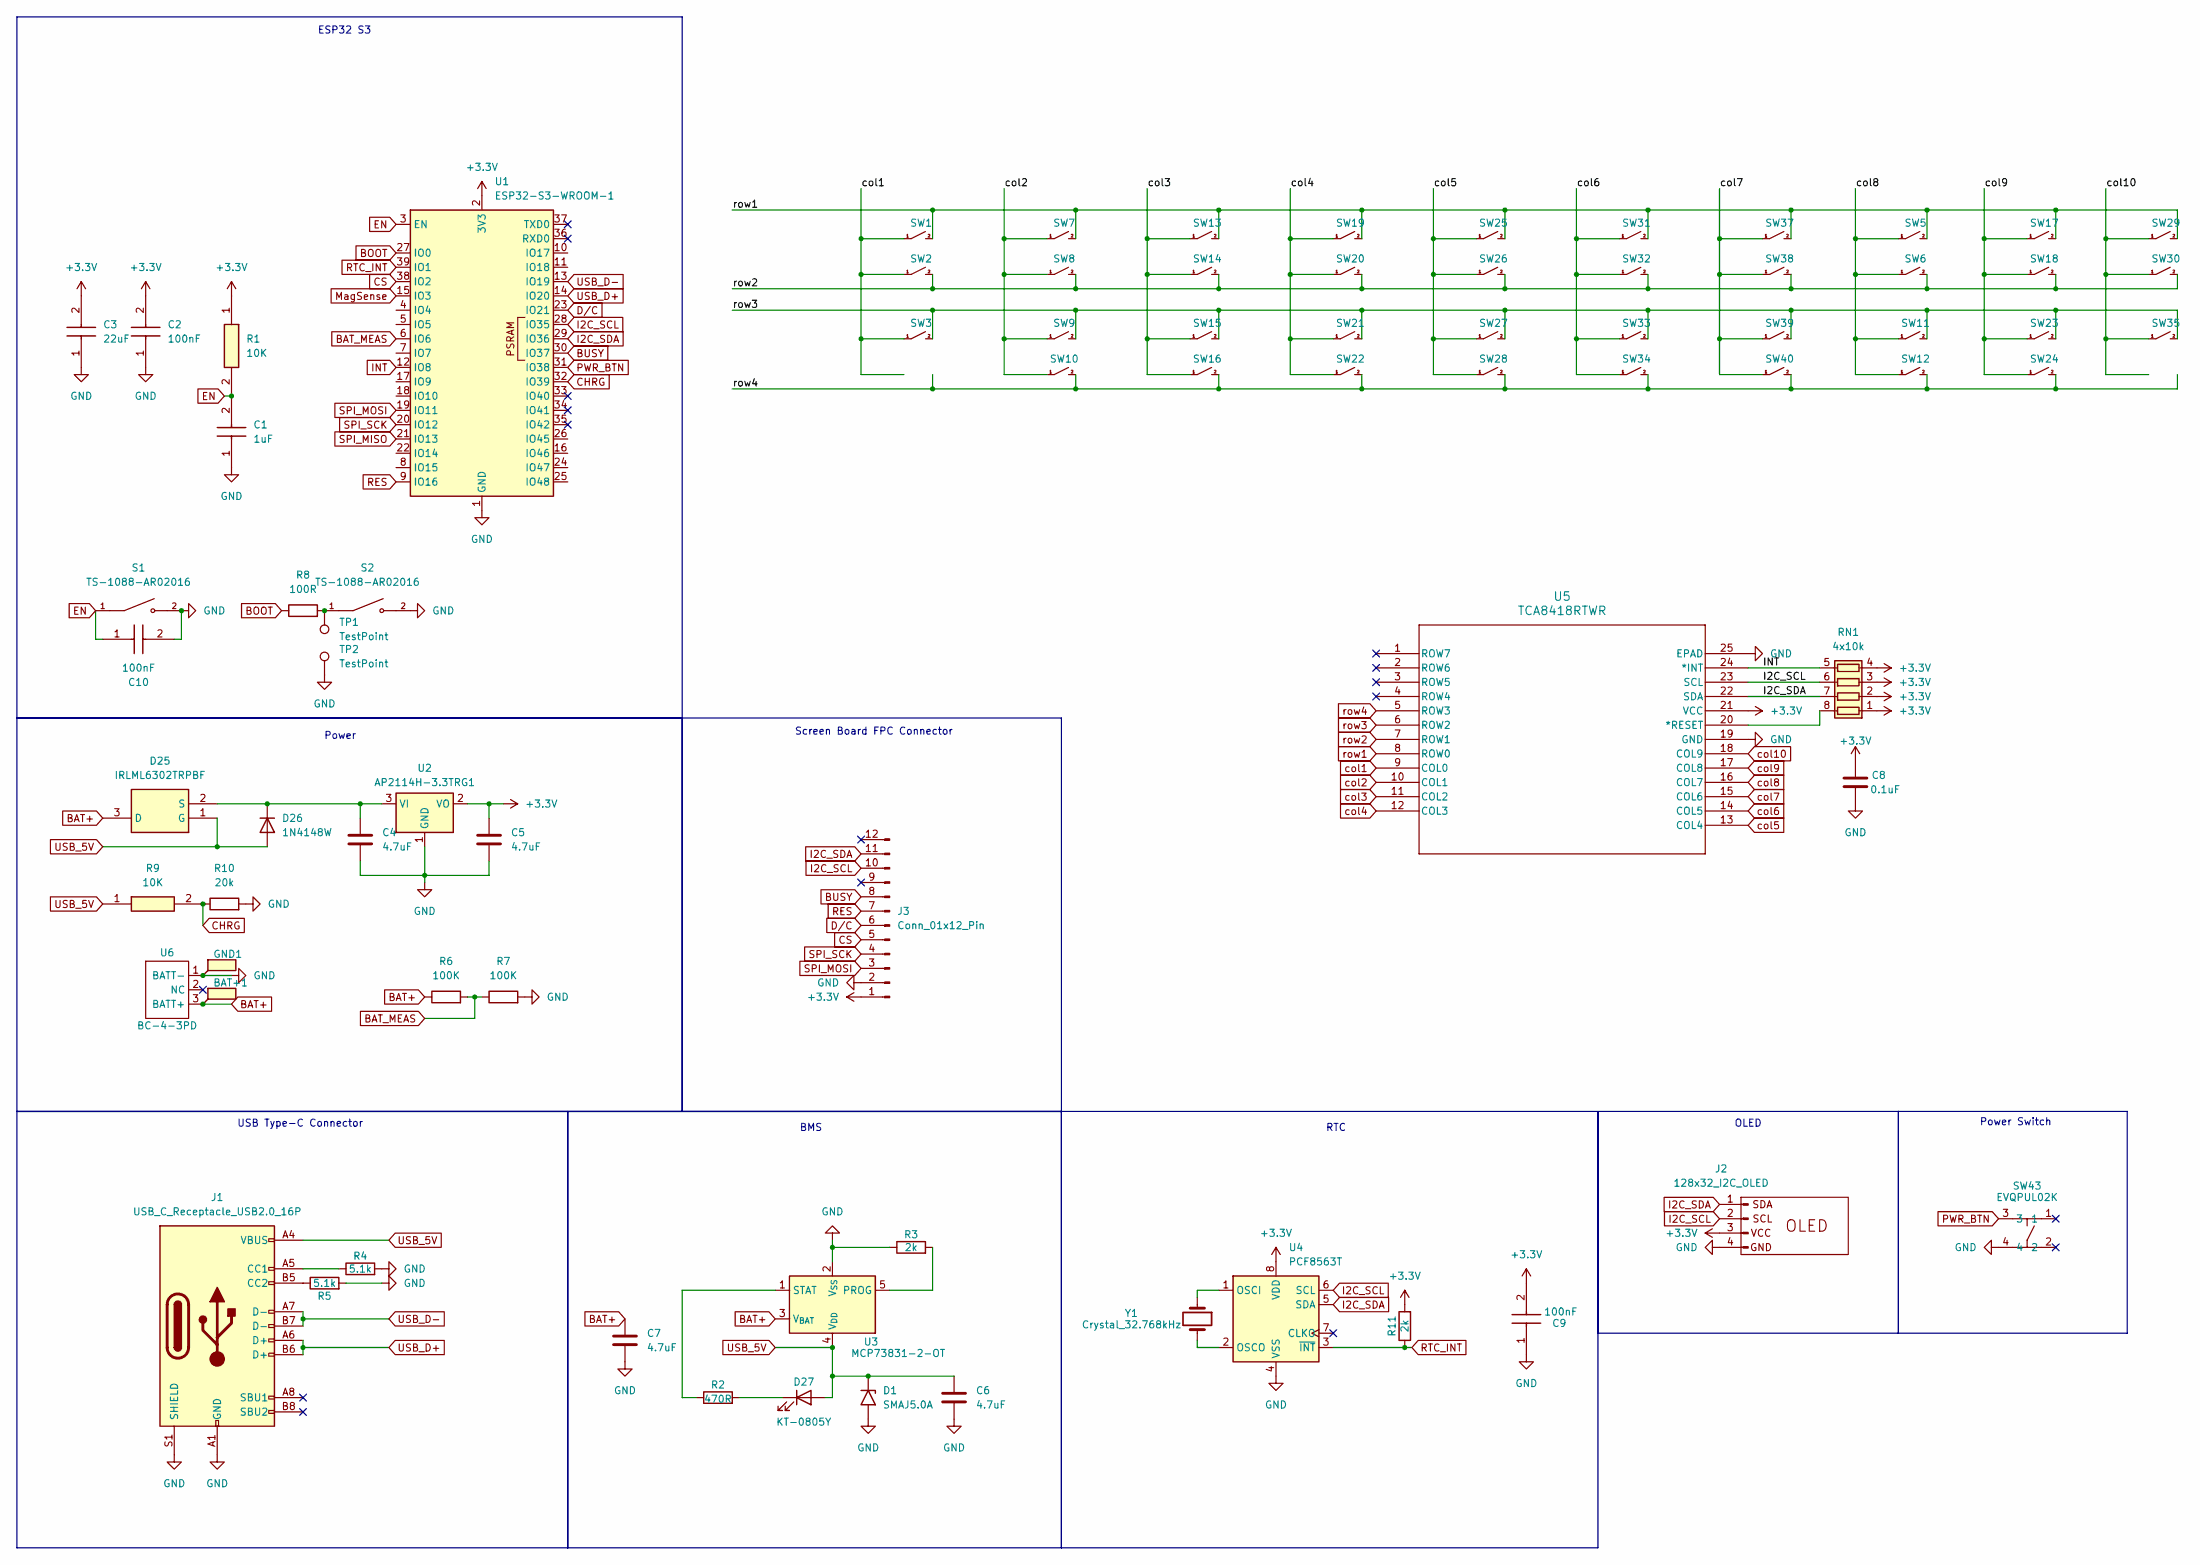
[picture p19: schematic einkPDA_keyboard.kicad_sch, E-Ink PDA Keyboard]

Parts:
BAT+1: TestPoint_Flag; TestPoint_Pad_D1.5mm
C1: 1uF; CAPC2012X135N; Mouser Part Number 187-CL21B105KBFNNNE
C2, C9, C10: 100nF; CAPC2012X95N; Mouser Part Number 603-CC805KRX7R9BB104
C3: 22uF; CAPC2012X140N; Mouser Part Number 187-CL21A226MAQNNNE
C4, C5, C6, C7: 4.7uF; C_0805_2012Metric; LCSC Part # CL21A475KAQNNNE
C8: 0.1uF; C_0402_1005Metric; LCSC Part # CL05B104KO5NNNC
D1: SMAJ5.0A; D_SMA
D25: IRLML6302TRPBF; SOT95P237X112-3N; Mouser Part Number 942-IRLML6302TRPBF
D26: 1N4148W; D_SOD-123; LCSC Part # 1N4148W
D27: KT-0805Y; LED_0805_2012Metric; LCSC Part # KT-0805Y
GND1: TestPoint_Flag; TestPoint_Pad_D1.5mm
J1: USB_C_Receptacle_USB2.0_16P; USB_C_Receptacle_G-Switch_GT-USB-7010ASV; LCSC Part # GT-USB-7010ASV
J2: 128x32_I2C_OLED; 128x32 I2C OLED
J3: Conn_01x12_Pin; AFC01-S12FCA-00; LCSC Part # AFC01-S12FCA-00:AFC01-S12FCA-00
R1, R9: 10K; R_0805_2012Metric; Mouser Part Number 303-0805W8F1002T5E
R2: 470R; R_0805_2012Metric; LCSC Part # 0805W8F4700T5E
R3, R11: 2k; R_0805_2012Metric; LCSC Part # 0805W8F2001T5E
R4, R5: 5.1k; R_0603_1608Metric; LCSC Part # 0603WAF5101T5E
R6, R7: 100K; R_1812_4532Metric; LCSC Part # FRC1812F1003TS
R8: 100R; R_1206_3216Metric; LCSC Part # 1206W4F1000T5E
R10: 20k; R_0603_1608Metric; LCSC Part # 0603WAF2002T5E
RN1: 4x10k; R_Array_Concave_4x0603; LCSC Part # 4D03WGJ0103T5E
S1, S2: TS-1088-AR02016; SW_TS-1088-AR02016; PARTREV N/A; LCSC Part # TS-1088-AR02016
SW1, SW2, SW3, SW5, SW6, SW7, SW8, SW9, SW10, SW11, SW12, SW13, SW14, SW15, SW16, SW17, SW18, SW19, SW20, SW21, SW22, SW23, SW24, SW25, SW26, SW27, SW28, SW29, SW30, SW31, SW32, SW33, SW34, SW35, SW37, SW38, SW39, SW40: contact_pad_SINGLE
SW43: EVQPUL02K; LCSC Part # EVQPUL02K
TP1, TP2: TestPoint; TestPoint_Pad_3.0x3.0mm
U1: ESP32-S3-WROOM-1; LCSC Part # ESP32-S3-WROOM-1
U2: AP2114H-3.3TRG1; SOT-223-3_TabPin2; LCSC Part # AP2114H-3.3TRG1
U3: MCP73831-2-OT; SOT-23-5; LCSC Part # MCP73831-2-OT
U4: PCF8563T; SOIC-8_3.9x4.9mm_P1.27mm
U5: TCA8418RTWR; RTW24_2P45X2P45; LCSC Part # TCA8418RTWR
U6: BC-4-3PD; LCSC Part # BC-4-3PD
Y1: Crystal_32.768kHz; Crystal_SMD_3215-2Pin_3.2x1.5mm; LCSC Part # XKXGI-SUA-32.768K

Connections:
+3.3V: C2.2, C3.2, C5.1, C8.1, C9.2, J2.3 (VCC), J3.1, R1.1, R11.2, RN1.1 (R1.1), RN1.2 (R2.1), RN1.3 (R3.1), RN1.4 (R4.1), U1.2 (3V3), U2.2 (VO), U4.8 (VDD), U5.21 (VCC)
BAT+: BAT+1.1, C7.1, D25.3 (D), R6.1, U3.3 (V_{BAT}), U6.3 (BATT+)
BAT_MEAS: R6.2, R7.1, U1.6 (IO6)
BOOT: R8.1, U1.27 (IO0)
BUSY: J3.8, U1.30 (IO37)
CHRG: R9.2, R10.1, U1.32 (IO39)
CS: J3.5, U1.38 (IO2)
D/C: J3.6, U1.23 (IO21)
EN: C1.2, C10.1, R1.2, S1.1, U1.3 (EN)
GND: C1.1, C2.1, C3.1, C4.2, C5.2, C6.2, C7.2, C8.2, C9.1, C10.2, D1.2 (A2), GND1.1, J1.A1 (GND), J1.A12 (GND), J1.B1 (GND), J1.B12 (GND), J1.S1 (SHIELD), J2.4 (GND), J3.2, R3.1, R4.2, R5.2, R7.2, R10.2, S1.2, S2.2, SW43.4, TP2.1, U1.1 (GND), U1.40 (GND), U1.41 (GND), U2.1 (GND), U3.2 (V_{SS}), U4.4 (VSS), U5.19 (GND), U5.25 (EPAD), U5.V, U6.1 (BATT-)
I2C_SCL: J2.2 (SCL), J3.10, RN1.6 (R3.2), U1.28 (IO35), U4.6 (SCL), U5.23 (SCL)
I2C_SDA: J2.1 (SDA), J3.11, RN1.7 (R2.2), U1.29 (IO36), U4.5 (SDA), U5.22 (SDA)
INT: RN1.5 (R4.2), U1.12 (IO8), U5.24 (*INT)
MagSense: U1.15 (IO3)
unnamed: C4.1, D25.2 (S), D26.1 (K), U2.3 (VI)
unnamed: D27.1 (K), R2.2
unnamed: J1.A5 (CC1), R4.1
unnamed: J1.B5 (CC2), R5.1
unnamed: R8.2, S2.1, TP1.1
unnamed: RN1.8 (R1.2), U5.20 (*RESET)
unnamed: R3.2, U3.5 (PROG)
unnamed: R2.1, U3.1 (STAT)
unnamed: U4.1 (OSCI), Y1.1
unnamed: U4.2 (OSCO), Y1.2
PWR_BTN: SW43.3, U1.31 (IO38)
RES: J3.7, U1.9 (IO16)
RTC_INT: R11.1, U1.39 (IO1), U4.3 (~INT)
SPI_MISO: U1.21 (IO13)
SPI_MOSI: J3.3, U1.19 (IO11)
SPI_SCK: J3.4, U1.20 (IO12)
USB_5V: C6.1, D1.1 (A1), D25.1 (G), D26.2 (A), D27.2 (A), J1.A4 (VBUS), J1.A9 (VBUS), J1.B4 (VBUS), J1.B9 (VBUS), R9.1, U3.4 (V_{DD})
USB_D+: J1.A6 (D+), J1.B6 (D+), U1.14 (IO20)
USB_D-: J1.A7 (D-), J1.B7 (D-), U1.13 (IO19)
col1: SW1.1, SW2.1, SW3.1, U5.9 (COL0)
col2: SW7.1, SW8.1, SW9.1, SW10.1, U5.10 (COL1)
col3: SW13.1, SW14.1, SW15.1, SW16.1, U5.11 (COL2)
col4: SW19.1, SW20.1, SW21.1, SW22.1, U5.12 (COL3)
col5: SW25.1, SW26.1, SW27.1, SW28.1, U5.13 (COL4)
col6: SW31.1, SW32.1, SW33.1, SW34.1, U5.14 (COL5)
col7: SW37.1, SW38.1, SW39.1, SW40.1, U5.15 (COL6)
col8: SW5.1, SW6.1, SW11.1, SW12.1, U5.16 (COL7)
col9: SW17.1, SW18.1, SW23.1, SW24.1, U5.17 (COL8)
col10: SW29.1, SW30.1, SW35.1, U5.18 (COL9)
row1: SW1.2, SW5.2, SW7.2, SW13.2, SW17.2, SW19.2, SW25.2, SW29.2, SW31.2, SW37.2, U5.8 (ROW0)
row2: SW2.2, SW6.2, SW8.2, SW14.2, SW18.2, SW20.2, SW26.2, SW30.2, SW32.2, SW38.2, U5.7 (ROW1)
row3: SW3.2, SW9.2, SW11.2, SW15.2, SW21.2, SW23.2, SW27.2, SW33.2, SW35.2, SW39.2, U5.6 (ROW2)
row4: SW10.2, SW12.2, SW16.2, SW22.2, SW24.2, SW28.2, SW34.2, SW40.2, U5.5 (ROW3)

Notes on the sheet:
ESP32 S3
RTC
Screen Board FPC Connector
Power
OLED
USB Type-C Connector
Power Switch
BMS

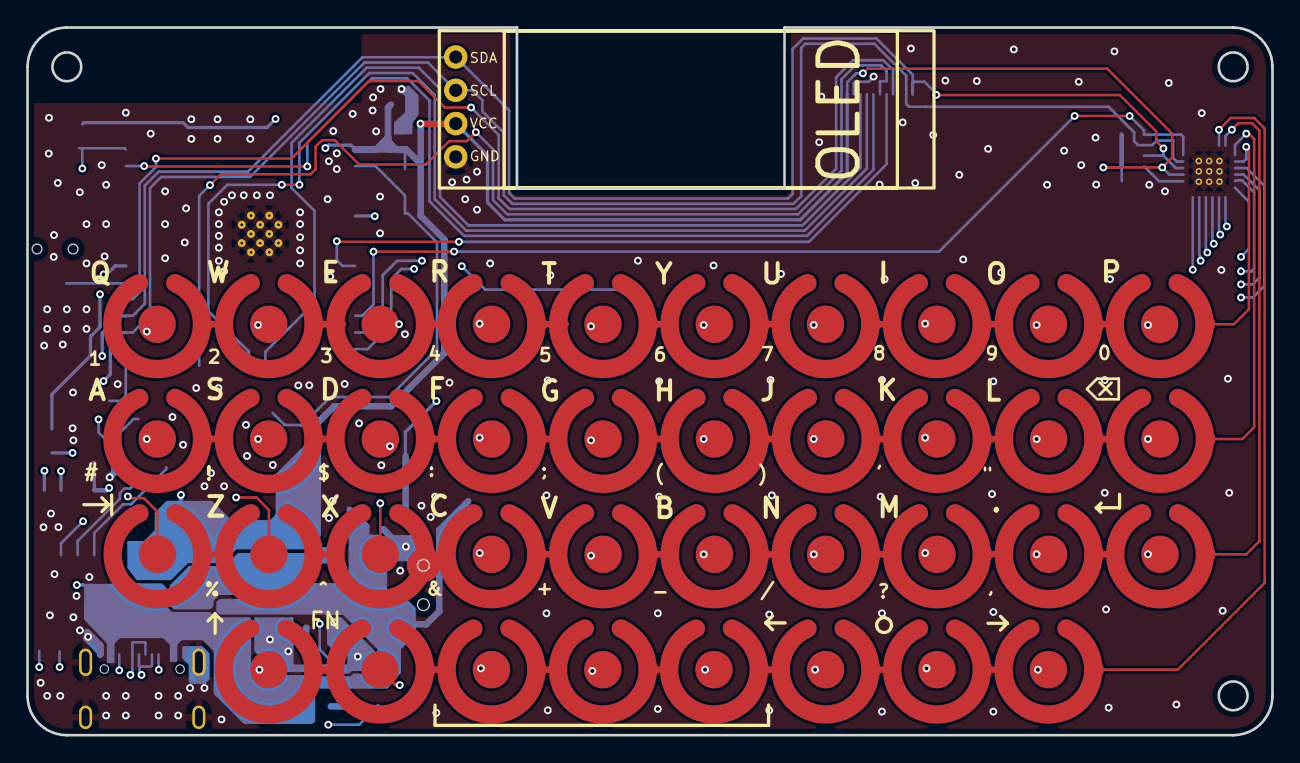
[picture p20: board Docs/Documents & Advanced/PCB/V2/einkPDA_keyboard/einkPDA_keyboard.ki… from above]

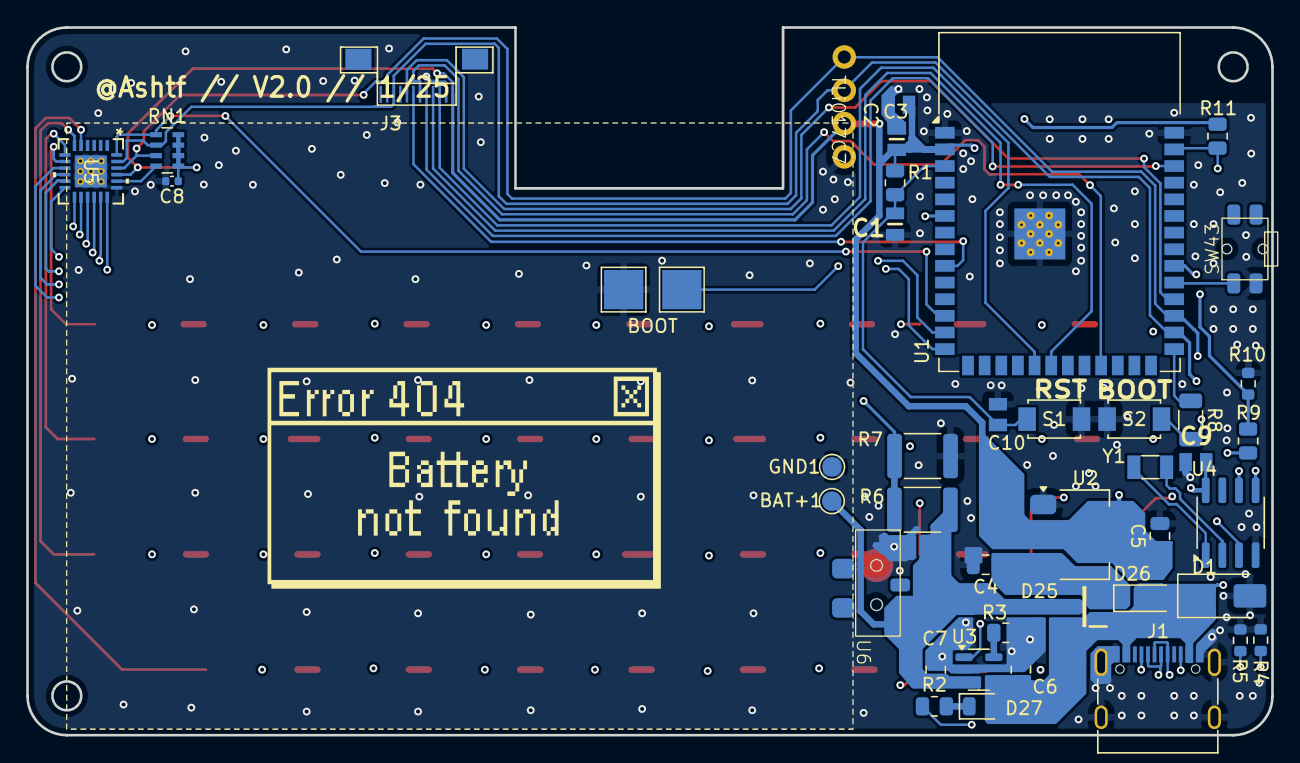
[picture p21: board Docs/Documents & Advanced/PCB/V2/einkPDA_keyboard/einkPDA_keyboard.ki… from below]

Board: 4 copper layers, 95.0 x 54.0 mm, 81 parts (42 on the bottom side), 45 nets.

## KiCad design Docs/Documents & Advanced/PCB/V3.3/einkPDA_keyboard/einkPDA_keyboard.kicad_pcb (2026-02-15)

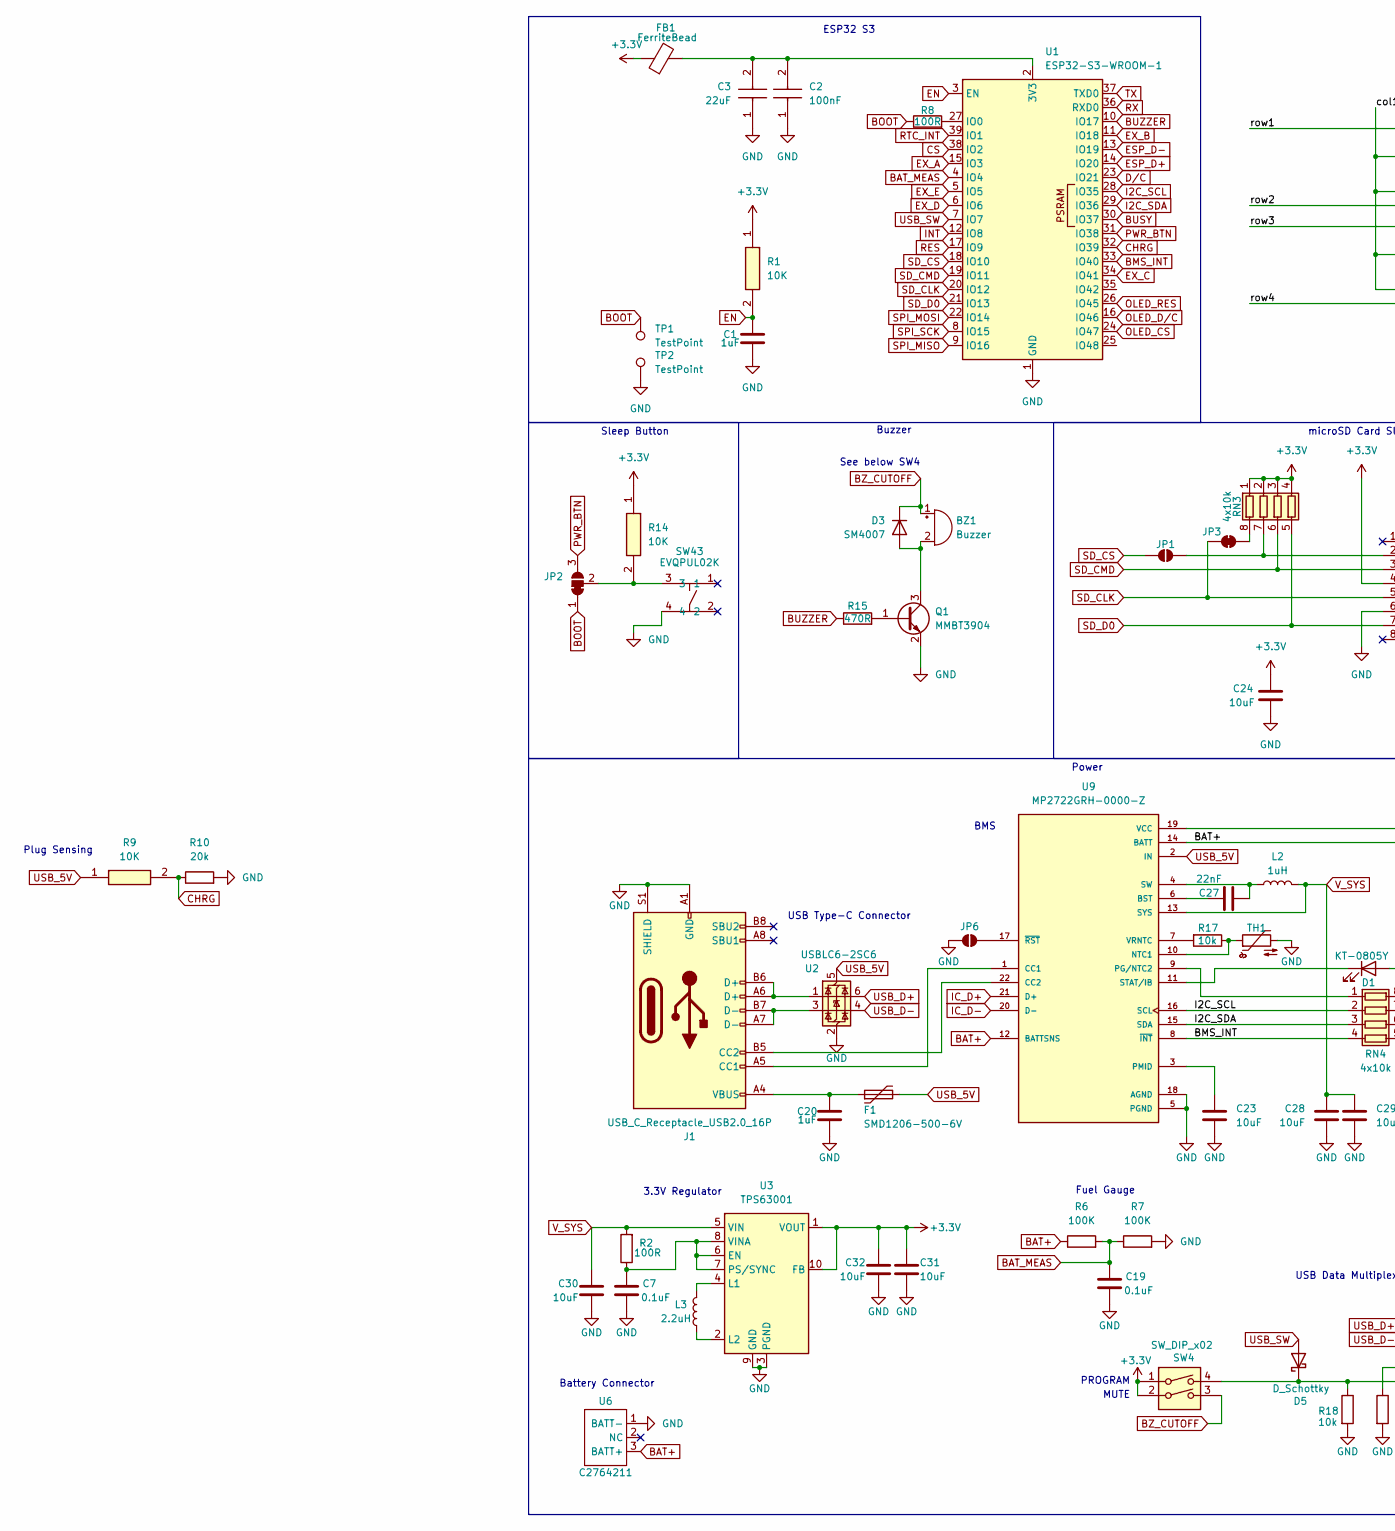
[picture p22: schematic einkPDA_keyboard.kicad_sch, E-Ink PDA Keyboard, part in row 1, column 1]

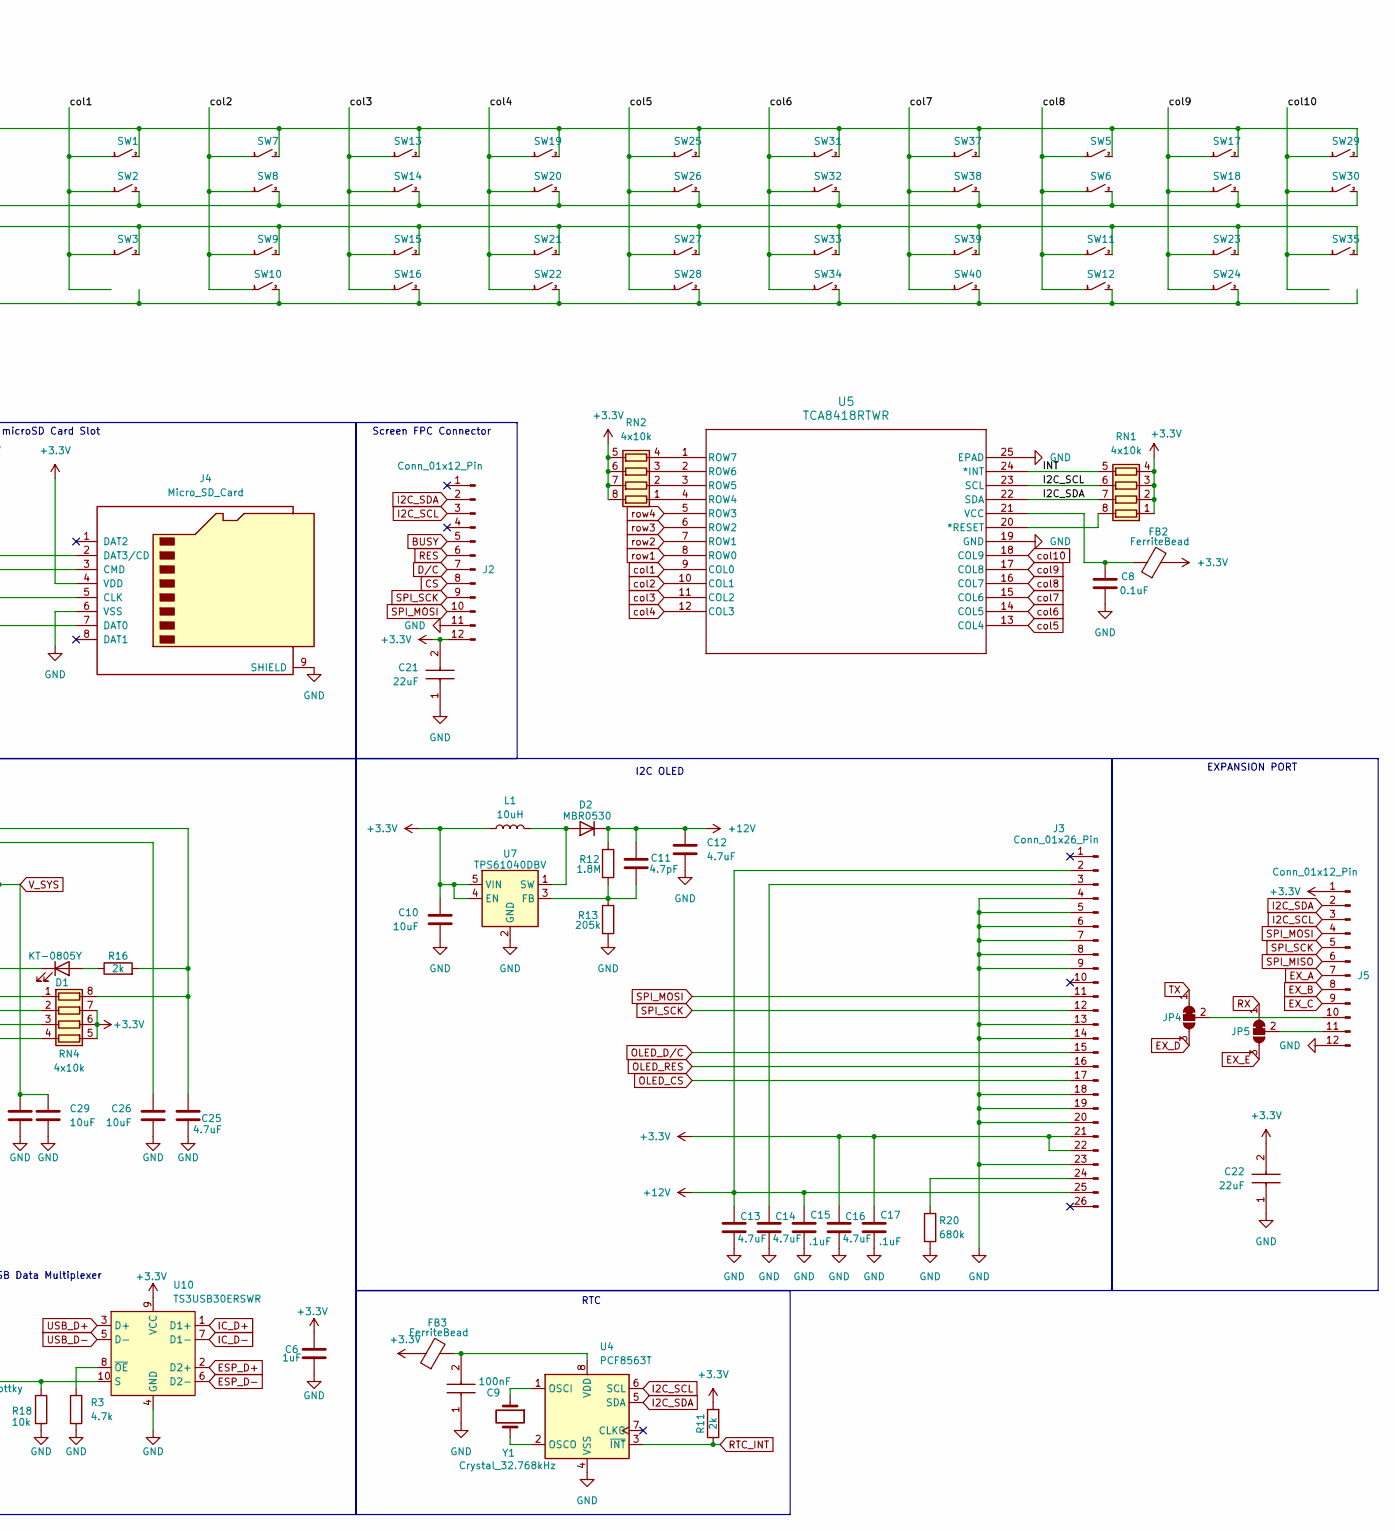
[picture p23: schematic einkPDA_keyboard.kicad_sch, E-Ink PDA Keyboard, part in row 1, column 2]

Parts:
BZ1: Buzzer; BUZ-SMD_3P_L5.0-W5.0-P3.50-TL; LCSC Part # C781883
C1, C6, C20: 1uF; C_0603_1608Metric; LCSC Part # C15849
C2, C9: 100nF; C_0805_2012Metric; Mouser Part Number 603-CC805KRX7R9BB104
C3, C21, C22: 22uF; C_0805_2012Metric; Mouser Part Number 187-CL21A226MAQNNNE
C7, C8, C19: 0.1uF; C_0402_1005Metric; LCSC Part # C1525
C10, C23, C26, C28, C29, C30, C31, C32: 10uF; C_0805_2012Metric; LCSC PART # C15850
C11: 4.7pF; C_0603_1608Metric; LCSC PART # C1669
C12, C13, C14, C16: 4.7uF; C_1206_3216Metric; LCSC PART # C29823
C15, C17: .1uF; C_0805_2012Metric; LCSC PART # C28233
C24: 10uF; C_0805_2012Metric; LCSC Part # C15850
C25: 4.7uF; C_0805_2012Metric; LCSC Part # C1779
C27: 22nF; C_0603_1608Metric; LCSC Part # C21122
D1: KT-0805Y; LED_0805_2012Metric; LCSC Part # C2296
D2: MBR0530; D_SOD-123; LCSC PART # C77336
D3: SM4007; D_SOD-123F; LCSC Part # C64898
D5: D_Schottky; D_SOD-323; LCSC Part # C191023
F1: SMD1206-500-6V; Fuse_1206_3216Metric; LCSC Part # C2760308
FB1, FB2, FB3: FerriteBead; L_0603_1608Metric; LCSC Part # C85831
J1: USB_C_Receptacle_USB2.0_16P; USB-TYPE-C-SMD_TYPE-C-16P-QTWT; LCSC Part # C5187472
J2, J5: Conn_01x12_Pin; AFC01-S12FCA-00; LCSC Part # C262661
J3: Conn_01x26_Pin; FPC-SMD_AFC24-S26FIA [DUAL-SIDE]; LCSC PART # C262684
J4: Micro_SD_Card; TF-SMD_503398-1892; LCSC Part # C428492
JP1, JP6: SolderJumper_2_Open; SolderJumper-2_P1.3mm_Open_RoundedPad1.0x1.5mm
JP2, JP4, JP5: SolderJumper_3_Bridged12; SolderJumper-3_P1.3mm_Bridged12_RoundedPad1.0x1.5mm
JP3: SolderJumper_2_Bridged; SolderJumper-2_P1.3mm_Bridged_RoundedPad1.0x1.5mm
L1: 10uH; L_Chilisin_BMRx00060630; LCSC PART # C5189958
L2: 1uH; L_Ferrocore_DLG-0504; LCSC Part # C2929426
L3: 2.2uH; L_Wurth_WE-LQSH-3012; LCSC Part # C19734
Q1: MMBT3904; SOT-23; LCSC Part # C20526
R1, R9, R14: 10K; R_0805_2012Metric; Mouser Part Number 303-0805W8F1002T5E
R2, R8: 100R; R_0603_1608Metric; LCSC Part # C22775
R3: 4.7k; R_0603_1608Metric; LCSC Part # C23162
R6, R7: 100K; R_0603_1608Metric; LCSC Part # C25803
R10: 20k; R_0603_1608Metric; LCSC Part # C4184
R11, R16: 2k; R_0805_2012Metric; LCSC Part # C17604
R12: 1.8M; R_0805_2012Metric; LCSC PART # C17399
R13: 205k; R_0805_2012Metric; LCSC PART # C218417
R15: 470R; R_0805_2012Metric; LCSC Part # C17710
R17: 10k; R_0805_2012Metric; LCSC Part # C17414
R18: 10k; R_0603_1608Metric; LCSC Part # C25804
R20: 680k; R_0805_2012Metric; LCSC PART # C17797
RN1, RN2, RN3, RN4: 4x10k; R_Array_Concave_4x0603; LCSC Part # C29718
SW1, SW2, SW3, SW5, SW6, SW7, SW8, SW9, SW10, SW11, SW12, SW13, SW14, SW15, SW16, SW17, SW18, SW19, SW20, SW21, SW22, SW23, SW24, SW25, SW26, SW27, SW28, SW29, SW30, SW31, SW32, SW33, SW34, SW35, SW37, SW38, SW39, SW40: contact_pad_SINGLE
SW4: SW_DIP_x02; 2X_DIP_DHN-02-V-TR; LCSC Part # C224995
SW43: EVQPUL02K; SW-SMD_TS24CA; LCSC Part # C393942
TH1: NTC; R_0603_1608Metric; LCSC Part # C76589
TP1, TP2: TestPoint; TestPoint_Pad_1.0x1.0mm
U1: ESP32-S3-WROOM-1; LCSC Part # C2913202
U2: USBLC6-2SC6; SOT-23-6; LCSC Part # C7519
U3: TPS63001; Texas_DRC0010J_ThermalVias; LCSC Part # C28060
U4: PCF8563T; SOIC-8_3.9x4.9mm_P1.27mm; LCSC Part # C7440
U5: TCA8418RTWR; RTW24_2P45X2P45; LCSC Part # C138713
U6: C2764211; JST_PH_2P_P2.00mm; LCSC Part # C2764211
U7: TPS61040DBV; SOT-23-5; LCSC PART # C7722
U9: MP2722GRH-0000-Z; IC_MP2722GRH-0000-Z; PARTREV 1.0; LCSC Part # C20099551
U10: TS3USB30ERSWR; UQFN-10_1.4x1.8mm_P0.4mm; LCSC Part # C73880
Y1: Crystal_32.768kHz; Crystal_SMD_3215-2Pin_3.2x1.5mm; LCSC Part # C5213671

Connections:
+3.3V: C6.2, C10.2, C16.1, C17.1, C21.2, C22.2, C24.1, C31.2, C32.2, FB1.1, FB2.2, FB3.1, J2.12, J3.21, J3.22, J4.4 (VDD), J5.1, L1.1, R1.1, R11.2, R14.1, RN1.1 (R1.1), RN1.2 (R2.1), RN1.3 (R3.1), RN1.4 (R4.1), RN2.5 (R4.2), RN2.6 (R3.2), RN2.7 (R2.2), RN2.8 (R1.2), RN3.1 (R1.1), RN3.2 (R2.1), RN3.3 (R3.1), RN3.4 (R4.1), RN4.5 (R4.2), RN4.6 (R3.2), RN4.7 (R2.2), SW4.1, SW4.2, U3.1 (VOUT), U3.10 (FB), U7.4 (EN), U7.5 (VIN), U10.9 (VCC)
+12V: C11.2, C12.1, C13.1, C15.1, D2.1 (K), J3.2, J3.25, R12.1
BAT+: C26.2, R6.1, U6.3 (BATT+), U9.12 (BATTSNS), U9.14 (BATT)
BAT_MEAS: C19.1, R6.2, R7.1, U1.4 (IO4)
BMS_INT: RN4.4 (R4.1), U1.33 (IO40), U9.8 (~INT)
BOOT: JP2.1 (A), R8.1, TP1.1
BUSY: J2.5, U1.30 (IO37)
BUZZER: R15.1, U1.10 (IO17)
BZ_CUTOFF: BZ1.1 (+), D3.1 (K), SW4.3
CHRG: R9.2, R10.1, U1.32 (IO39)
CS: J2.8, U1.38 (IO2)
D/C: J2.7, U1.23 (IO21)
EN: C1.2, R1.2, U1.3 (EN)
ESP_D+: U1.14 (IO20), U10.2 (D2+)
ESP_D-: U1.13 (IO19), U10.6 (D2-)
EX_A: J5.7, U1.15 (IO3)
EX_B: J5.8, U1.11 (IO18)
EX_C: J5.9, U1.34 (IO41)
EX_D: JP4.3 (B), U1.6 (IO6)
EX_E: JP5.3 (B), U1.5 (IO5)
GND: C1.1, C2.1, C3.1, C6.1, C7.2, C8.2, C9.1, C10.1, C12.2, C13.2, C14.2, C15.2, C16.2, C17.2, C19.2, C20.1, C21.1, C22.1, C23.1, C24.2, C25.2, C26.1, C28.1, C29.1, C30.1, C31.1, C32.1, J1.A1 (GND), J1.A12 (GND), J1.B1 (GND), J1.B12 (GND), J1.S1 (SHIELD), J2.11, J3.4, J3.5, J3.6, J3.7, J3.8, J3.9, J3.13, J3.14, J3.18, J3.19, J3.20, J3.23, J4.6 (VSS), J4.9 (SHIELD), J5.12, JP6.1 (A), Q1.2 (E), R3.2, R7.2, R10.2, R13.2, R18.2, R20.2, SW43.4, TH1.2, TP2.1, U1.1 (GND), U1.40 (GND), U1.41 (GND), U2.2 (GND), U3.3 (PGND), U3.9 (GND), U3.11 (PGND), U4.4 (VSS), U5.19 (GND), U5.25 (EPAD), U5.V, U6.1 (BATT-), U7.2 (GND), U9.5 (PGND), U9.18 (AGND), U10.4 (GND)
I2C_SCL: J2.3, J5.3, RN1.6 (R3.2), RN4.2 (R2.1), U1.28 (IO35), U4.6 (SCL), U5.23 (SCL), U9.16 (SCL)
I2C_SDA: J2.2, J5.2, RN1.7 (R2.2), RN4.3 (R3.1), U1.29 (IO36), U4.5 (SDA), U5.22 (SDA), U9.15 (SDA)
IC_D+: U9.21 (D+), U10.1 (D1+)
IC_D-: U9.20 (D-), U10.7 (D1-)
INT: RN1.5 (R4.2), U1.12 (IO8), U5.24 (*INT)
unnamed: BZ1.2 (-), D3.2 (A), Q1.3 (C)
unnamed: C20.2, F1.1, J1.A4 (VBUS), J1.A9 (VBUS), J1.B4 (VBUS), J1.B9 (VBUS)
unnamed: D1.2 (A), R16.1
unnamed: D1.1 (K), U9.11 (STAT/IB)
unnamed: D2.2 (A), L1.2, U7.1 (SW)
unnamed: D5.1 (K), R18.1, SW4.4, U10.10 (S)
unnamed: J1.A5 (CC1), U9.1 (CC1)
unnamed: J1.B5 (CC2), U9.22 (CC2)
unnamed: J1.A6 (D+), J1.B6 (D+), U2.1 (I/O1)
unnamed: J1.A7 (D-), J1.B7 (D-), U2.3 (I/O2)
unnamed: C14.1, J3.3
unnamed: J3.24, R20.1
unnamed: J4.2 (DAT3/CD), JP1.2 (B), RN3.7 (R2.2)
unnamed: J5.10, JP4.2 (C)
unnamed: J5.11, JP5.2 (C)
unnamed: JP2.2 (C), R14.2, SW43.3
unnamed: JP3.2 (B), RN3.8 (R1.2)
unnamed: JP6.2 (B), U9.17 (~RST)
unnamed: Q1.1 (B), R15.2
unnamed: RN1.8 (R1.2), U5.20 (*RESET)
unnamed: RN2.1 (R1.1), U5.4 (ROW4)
unnamed: RN2.2 (R2.1), U5.3 (ROW5)
unnamed: RN2.3 (R3.1), U5.2 (ROW6)
unnamed: RN2.4 (R4.1), U5.1 (ROW7)
unnamed: RN4.1 (R1.1), U9.9 (PG/NTC2)
unnamed: C25.1, R16.2, RN4.8 (R1.2), U9.19 (VCC)
unnamed: C2.2, C3.2, FB1.2, U1.2 (3V3)
unnamed: R8.2, U1.27 (IO0)
unnamed: C7.1, R2.1, U3.6 (EN), U3.7 (PS/SYNC), U3.8 (VINA)
unnamed: L3.1, U3.4 (L1)
unnamed: L3.2, U3.2 (L2)
unnamed: U4.1 (OSCI), Y1.1
unnamed: U4.2 (OSCO), Y1.2
unnamed: C9.2, FB3.2, U4.8 (VDD)
unnamed: C8.1, FB2.1, U5.21 (VCC)
unnamed: C11.1, R12.2, R13.1, U7.3 (FB)
unnamed: C27.2, U9.6 (BST)
unnamed: R17.1, TH1.1, U9.10 (NTC1)
unnamed: C23.2, U9.3 (PMID)
unnamed: C27.1, L2.1, U9.4 (SW)
unnamed: R17.2, U9.7 (VRNTC)
unnamed: R3.1, U10.8 (~OE)
OLED_CS: J3.17, U1.24 (IO47)
OLED_D/C: J3.15, U1.16 (IO46)
OLED_RES: J3.16, U1.26 (IO45)
PWR_BTN: JP2.3 (B), U1.31 (IO38)
RES: J2.6, U1.17 (IO9)
RTC_INT: R11.1, U1.39 (IO1), U4.3 (~INT)
RX: JP5.1 (A), U1.36 (RXD0)
SD_CLK: J4.5 (CLK), JP3.1 (A), U1.20 (IO12)
SD_CMD: J4.3 (CMD), RN3.6 (R3.2), U1.19 (IO11)
SD_CS: JP1.1 (A), U1.18 (IO10)
SD_D0: J4.7 (DAT0), RN3.5 (R4.2), U1.21 (IO13)
SPI_MISO: J5.6, U1.9 (IO16)
SPI_MOSI: J2.10, J3.11, J5.4, U1.22 (IO14)
SPI_SCK: J2.9, J3.12, J5.5, U1.8 (IO15)
TX: JP4.1 (A), U1.37 (TXD0)
USB_5V: F1.2, R9.1, U2.5 (VBUS), U9.2 (IN)
USB_D+: U2.6 (I/O1), U10.3 (D+)
USB_D-: U2.4 (I/O2), U10.5 (D-)
USB_SW: D5.2 (A), U1.7 (IO7)
V_SYS: C28.2, C29.2, C30.2, L2.2, R2.2, U3.5 (VIN), U9.13 (SYS)
col1: SW1.1, SW2.1, SW3.1, U5.9 (COL0)
col2: SW7.1, SW8.1, SW9.1, SW10.1, U5.10 (COL1)
col3: SW13.1, SW14.1, SW15.1, SW16.1, U5.11 (COL2)
col4: SW19.1, SW20.1, SW21.1, SW22.1, U5.12 (COL3)
col5: SW25.1, SW26.1, SW27.1, SW28.1, U5.13 (COL4)
col6: SW31.1, SW32.1, SW33.1, SW34.1, U5.14 (COL5)
col7: SW37.1, SW38.1, SW39.1, SW40.1, U5.15 (COL6)
col8: SW5.1, SW6.1, SW11.1, SW12.1, U5.16 (COL7)
col9: SW17.1, SW18.1, SW23.1, SW24.1, U5.17 (COL8)
col10: SW29.1, SW30.1, SW35.1, U5.18 (COL9)
row1: SW1.2, SW5.2, SW7.2, SW13.2, SW17.2, SW19.2, SW25.2, SW29.2, SW31.2, SW37.2, U5.8 (ROW0)
row2: SW2.2, SW6.2, SW8.2, SW14.2, SW18.2, SW20.2, SW26.2, SW30.2, SW32.2, SW38.2, U5.7 (ROW1)
row3: SW3.2, SW9.2, SW11.2, SW15.2, SW21.2, SW23.2, SW27.2, SW33.2, SW35.2, SW39.2, U5.6 (ROW2)
row4: SW10.2, SW12.2, SW16.2, SW22.2, SW24.2, SW28.2, SW34.2, SW40.2, U5.5 (ROW3)

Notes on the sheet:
Plug Sensing
ESP32 S3
RTC
Screen FPC Connector
PROGRAM
Buzzer
Battery Connector
See below SW4
Power
microSD Card Slot
Fuel Gauge
USB Data Multiplexer
USB Type-C Connector
3.3V Regulator
EXPANSION PORT
Sleep Button
MUTE
BMS
I2C OLED

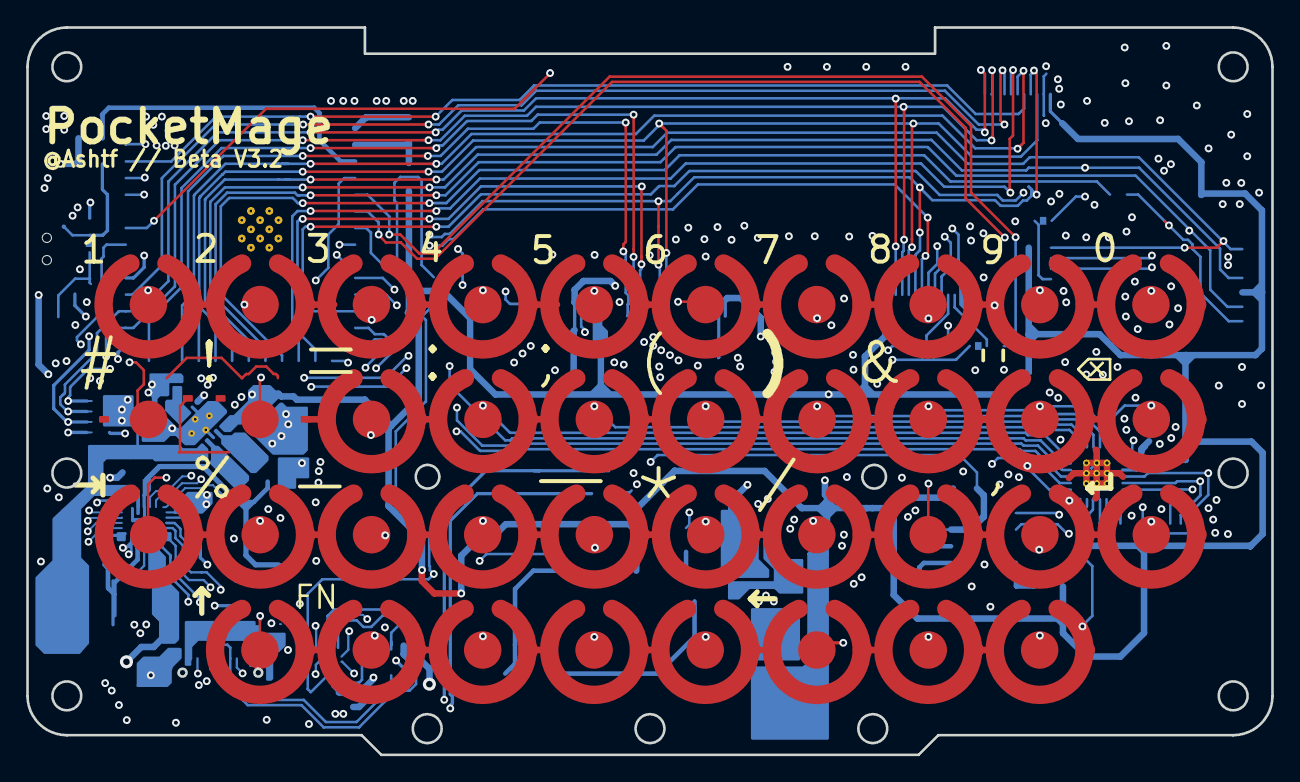
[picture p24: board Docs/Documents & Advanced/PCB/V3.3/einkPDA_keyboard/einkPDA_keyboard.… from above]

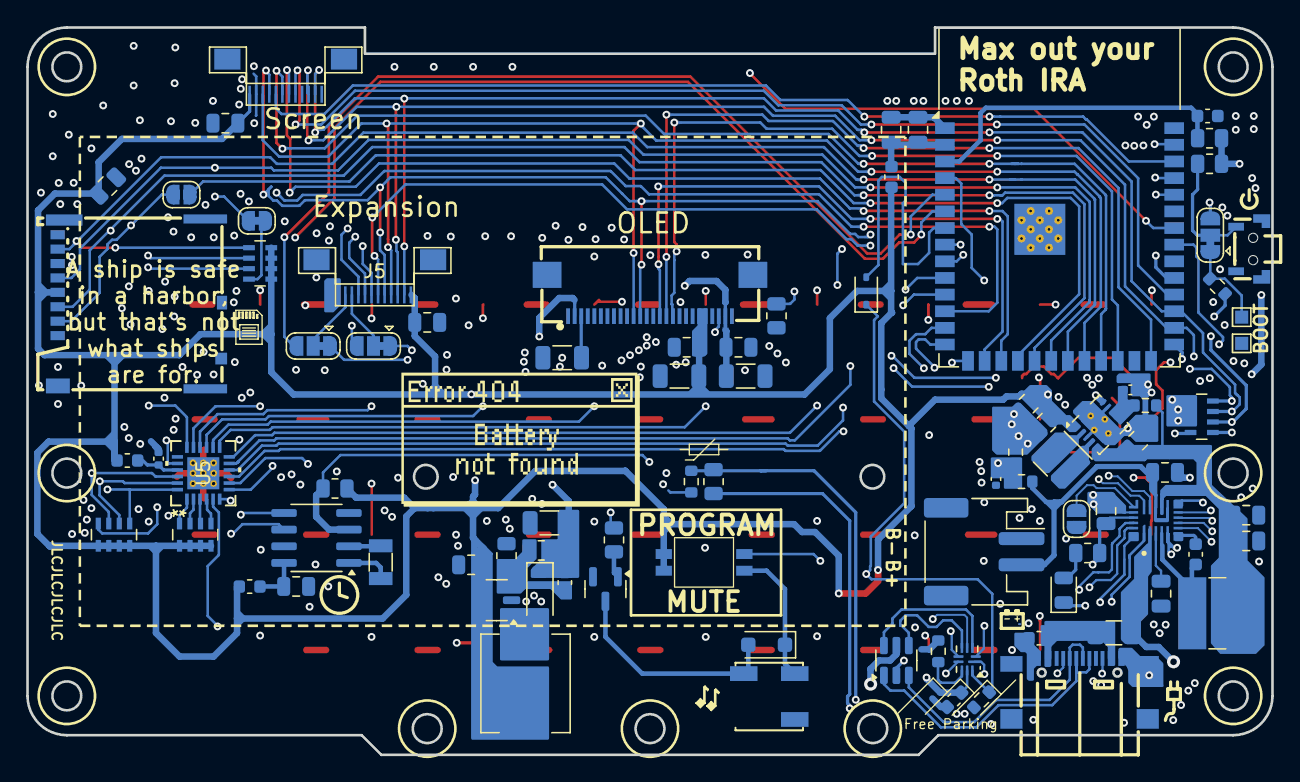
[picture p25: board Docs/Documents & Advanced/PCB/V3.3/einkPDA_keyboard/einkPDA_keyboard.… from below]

Board: 4 copper layers, 95.0 x 55.5 mm, 125 parts (87 on the bottom side), 101 nets.

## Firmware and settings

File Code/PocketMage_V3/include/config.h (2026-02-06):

#ifndef CONFIG_H
#define CONFIG_H

// OTA App
// Is this an OTA APP? // OTA_APP: set -DOTA_APP_FLAG=1 in platformio.ini
#if OTA_APP_FLAG
#define OTA_APP true
#else
#define OTA_APP false
#endif

// CONFIGURATION & SETTINGS
////////////////////////////////////////////////////////////////////////////////////////////////////////////////////////////|
#define KB_COOLDOWN 50                          // Keypress cooldown
#define FULL_REFRESH_AFTER 5                    // Full refresh after N partial refreshes (CHANGE WITH CAUTION)
#define MAX_FILES 10                            // Number of files to store
#define FORMAT_SPIFFS_IF_FAILED true            // Format the SPIFFS filesystem if mount fails
#define SLEEPMODE "TEXT"                        // TEXT, SPLASH, CLOCK
#define TXT_APP_STYLE 1                         // 0: Old Style (NOT SUPPORTED), 1: New Style
#define SET_CLOCK_ON_UPLOAD false               // Should system clock be set automatically on code upload?
#define TOUCH_TIMEOUT_MS 1200                   // Delay after scrolling to return to typing mode (ms)
#define SYS_METADATA_FILE "/sys/SDMMC_META.txt" // File path to the file system metadata file
#define POWER_SAVE_FREQ 40                      // CPU freq for power save mode
#define IDLE_TIME 20000                         // time to wait for mage idle (ms)
////////////////////////////////////////////////////////////////////////////////////////////////////////////////////////////|

// PIN DEFINITION

#define I2C_SCL       35
#define I2C_SDA       36
#define MPR121_ADDR   0x5A
#define MP2722_ADDR   0x3F
#define USB_MUX_PIN   7

#define KB_IRQ        8
//#define PWR_BTN       38  // V3.0
#define PWR_BTN       0     // V3.2
#define BAT_SENS      4
#define CHRG_SENS     39
#define RTC_INT       1 

// SPI
#define SPI_MOSI      14
#define SPI_SCK       15

// OLED
#define OLED_CS       47
#define OLED_DC       46
#define OLED_RST      45

// E Ink
#define EPD_CS        2
#define EPD_DC        21
#define EPD_RST       9
#define EPD_BUSY      37

// SDMMC mode
#define SD_CLK        12
#define SD_CMD        11
#define SD_D0         13

// SDSPI mode
#define SD_CS         10
#define SD_MOSI       11
#define SD_SCK        12
#define SD_MISO       13

#define BZ_PIN        17

// ===================== SYSTEM SETTINGS =====================
// Persistent preferences
extern int TIMEOUT;              // Auto sleep timeout (seconds)
extern bool DEBUG_VERBOSE;       // Extra debug output
extern bool SYSTEM_CLOCK;        // Show clock on screen
extern bool SHOW_YEAR;           // Show year in clock
extern bool SAVE_POWER;          // Enable power saving mode
extern bool ALLOW_NO_MICROSD;    // Allow running without SD card
extern bool HOME_ON_BOOT;        // Start home app on boot
extern int OLED_BRIGHTNESS;      // OLED brightness (0-255)
extern int OLED_MAX_FPS;         // OLED max FPS
extern bool SD_SPI_COMPATIBILITY;

#endif

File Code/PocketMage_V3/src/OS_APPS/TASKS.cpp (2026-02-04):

// ooooooooooooo       .o.        .oooooo..o oooo    oooo  .oooooo..o //
// 8'   888   `8      .888.      d8P'    `Y8 `888   .8P'  d8P'    `Y8 //
//      888          .8"888.     Y88bo.       888  d8'    Y88bo.      //
//      888         .8' `888.     `"Y8888o.   88888[       `"Y8888o.  //
//      888        .88ooo8888.        `"Y88b  888`88b.         `"Y88b //
//      888       .8'     `888.  oo     .d8P  888  `88b.  oo     .d8P //
//     o888o     o88o     o8888o 8""88888P'  o888o  o888o 8""88888P'  //  

#include <globals.h>
#include "esp32-hal-log.h"
#include "esp_log.h"
#if !OTA_APP // POCKETMAGE_OS
enum TasksState { TASKS0, TASKS0_NEWTASK, TASKS1, TASKS1_EDITTASK };
TasksState CurrentTasksState = TASKS0;

static constexpr const char* TAG = "TASKS";

static String currentWord = "";
static String currentLine = "";
uint8_t newTaskState = 0;
uint8_t editTaskState = 0;
String newTaskName = "";
String newTaskDueDate = "";
uint8_t selectedTask = 0;

void TASKS_INIT() {
  CurrentAppState = TASKS;
  CurrentTasksState = TASKS0;
  EINK().forceSlowFullUpdate(true);
  newState = true;
}

void sortTasksByDueDate(std::vector<std::vector<String>> &tasks) {
  std::sort(tasks.begin(), tasks.end(), [](const std::vector<String> &a, const std::vector<String> &b) {
    return a[1] < b[1]; // Compare dueDate strings
  });
}

void updateTasksFile() {
  SDActive = true;
  pocketmage::setCpuSpeed(240);
  delay(50);
  // Clear the existing tasks file first
  PM_SDAUTO().delFile("/sys/tasks.txt");

  // Iterate through the tasks vector and append each task to the file
  for (size_t i = 0; i < tasks.size(); i++) {
    // Create a string from the task's attributes with "|" delimiter
    String taskInfo = tasks[i][0] + "|" + tasks[i][1] + "|" + tasks[i][2] + "|" + tasks[i][3];
    
    // Append the task info to the file
    PM_SDAUTO().appendToFile("/sys/tasks.txt", taskInfo);
  }

  if (SAVE_POWER) pocketmage::setCpuSpeed(POWER_SAVE_FREQ);
  SDActive = false;
}

void addTask(String taskName, String dueDate, String priority, String completed) {
  String taskInfo = taskName+"|"+dueDate+"|"+priority+"|"+completed;
  updateTaskArray();
  tasks.push_back({taskName, dueDate, priority, completed});
  sortTasksByDueDate(tasks);
  updateTasksFile();
}

void updateTaskArray() {
  SDActive = true;
  pocketmage::setCpuSpeed(240);
  delay(50);
  File file = global_fs->open("/sys/tasks.txt", "r"); // Open the text file in read mode
  if (!file) {
    ESP_LOGE(TAG, "Failed to open file to read: %s", file.path());
    return;
  }

  tasks.clear(); // Clear the existing vector before loading the new data

  // Loop through the file, line by line
  while (file.available()) {
    String line = file.readStringUntil('\n');  // Read a line from the file
    line.trim();  // Remove any extra spaces or newlines
    
    // Skip empty lines
    if (line.length() == 0) {
      continue;
    }

    // Split the line into individual parts using the delimiter '|'
    uint8_t delimiterPos1 = line.indexOf('|');
    uint8_t delimiterPos2 = line.indexOf('|', delimiterPos1 + 1);
    uint8_t delimiterPos3 = line.indexOf('|', delimiterPos2 + 1);

    // Extract task name, due date, priority, and completed status
    String taskName  = line.substring(0, delimiterPos1);
    String dueDate   = line.substring(delimiterPos1 + 1, delimiterPos2);
    String priority  = line.substring(delimiterPos2 + 1, delimiterPos3);
    String completed = line.substring(delimiterPos3 + 1);

    // Add the task to the vector
    tasks.push_back({taskName, dueDate, priority, completed});
  }

  file.close();  // Close the file

  if (SAVE_POWER) pocketmage::setCpuSpeed(POWER_SAVE_FREQ);
  SDActive = false;
}


void deleteTask(int index) {
  if (index >= 0 && index < tasks.size()) {
    tasks.erase(tasks.begin() + index);
  }
}

String convertDateFormat(String yyyymmdd) {
  if (yyyymmdd.length() != 8) {
    ESP_LOGE(TAG, "Invalid Date: %s", yyyymmdd.c_str());
    return "Invalid";
  }

  String year = yyyymmdd.substring(2, 4);  // Get last two digits of the year
  String month = yyyymmdd.substring(4, 6);
  String day = yyyymmdd.substring(6, 8);

  return month + "/" + day + "/" + year;
}

void processKB_TASKS() {
  OLED().setPowerSave(false);
  int currentMillis = millis();
  disableTimeout = false;
  char inchar;

  switch (CurrentTasksState) {
    case TASKS0:
      KB().setKeyboardState(FUNC);
      //Make keyboard only updates after cooldown
      if (currentMillis - KBBounceMillis >= KB_COOLDOWN) {  
        inchar = KB().updateKeypress();
        //No char recieved
        if (inchar == 0);
        //BKSP Recieved
        else if (inchar == 127 || inchar == 8 || inchar == 12) {
          HOME_INIT();
          break;
        }
        // NEW TASK
        else if (inchar == '/' || inchar == 'n' || inchar == 'N') {
          CurrentTasksState = TASKS0_NEWTASK;
          KB().setKeyboardState(NORMAL);
          newTaskState = 0;
          newState = true;
          break;
        }
        // SELECT A TASK
        else if (inchar >= '0' && inchar <= '9') {
          int taskIndex = (inchar == '0') ? 10 : (inchar - '1');  // Adjust for 1-based input

          // SET SELECTED TASK
          if (taskIndex < tasks.size()) {
            selectedTask = taskIndex;
            // GO TO TASKS1
            CurrentTasksState = TASKS1;
            editTaskState = 0;
            newState = true;
          }
        }

        currentMillis = millis();
        //Make sure oled only updates at 60fps
        if (currentMillis - OLEDFPSMillis >= (1000/OLED_MAX_FPS)) {
          OLEDFPSMillis = currentMillis;
          OLED().oledWord(currentWord);
        }
        KBBounceMillis = currentMillis;
      }
      break;
    case TASKS0_NEWTASK:
      if (newTaskState == 1) KB().setKeyboardState(FUNC);
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

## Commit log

2025-12-03 initial addition of frames, testing of buzzer PWM control
2025-12-11 oops remove print
2026-02-03 change dual SPI setup (screens working)
2026-02-04 Implement dynamic filesystem
    Note: USB app not working yet
    [TASKS.cpp]
2026-02-04 Add SD Card Formatting Guide for PocketMage
    This document provides a comprehensive guide for formatting SD cards compatible with the PocketMage device, including instructions for Windows, macOS, and Linux users.
2026-02-06 Framework for POTION IDE
2026-02-15 Add and reorganize docs
    [0805W8F1002T5E.SchLib, 0805W8F1002T5E.stp, C262684 v2.step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]
